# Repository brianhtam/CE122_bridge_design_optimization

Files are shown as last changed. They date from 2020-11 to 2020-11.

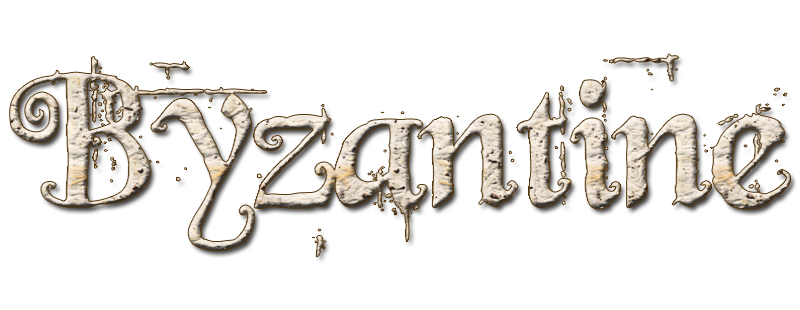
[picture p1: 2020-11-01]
Design Dwg/drawing set 0426/byzantine-553485bc295ea.png

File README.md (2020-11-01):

# University of California, Berkeley

CE 122/123L Bridge Design

# Project Team



**Brian Tam**

**Omar Natouf**

**Shien Jinn Sam**

**Yanlong Ma**

**Yiqiu Zhang**

##

## **Table of Contents**

**[Table of Contents](#_f7xz7zsjwv2b) 2**

**[Letter of Transmittal](#_xhpnu6qg48wh) 3**

**[Financial Proposal](#_yx2o4zm9mrrj) 5**

[Overview](#_aqlsbv7fhpvq) 5

[Cable Costs](#_o17h3vvil44b) 5

[Deck Costs](#_dh3ztm5w0bez) 6

[Tower Costs](#_s972q8khpf2) 7

[Total Costs per Material](#_b7bybf2inuhd) 7

**[Technical Proposal](#_st1wws806zix) 8**

[General Project Description](#_1rhd1lc7gizo) 8

[Structural system](#_jgtkp7muid0m) 8

[Loading criteria and assumption](#_r6sjckvptk4v) 9

[Materials](#_yjlk839i16uc) 9

[Geotechnical](#_2ylj1osfg9p6) 10

[Design of special conditions / elements](#_7mhoiul97b6n) 10

[i.Superstructure](#_jvqc4qcoaiqa) 10

[ii.Front Cable](#_czys5ons2eut) 17

[iii.Back Cable](#_febw9687uqyy) 18

[iv.Pylon](#_nsjcbofvci24) 18

[Foundation](#_ym1lxph0stmt) 19

[East side foundation](#_q6vr1uheaz0p) 19

[Abutment](#_579va1yglpyk) 20

[Constructability](#_equ7trvwbor7) 25

**[Appendix](#_nmife3doaf2) 32**

##

1.
## Letter of Transmittal

Davis 502

Berkeley, CA 94720

Yanlong Ma, PhD

April 28th 2017

Professor Stephen Mahin

Professor of Civil Engineering,

University of California, Berkeley

Berkeley, Ca 94720

Dear Professor Mahin,

We are Byzantine, a structural engineering firm specializing in bridge design and construction. It has come to our attention recently, that there is an open design bid for the proposed J St. Bridge. Our team, consisting of professionally licensed structural engineers, is writing to submit our design proposal for the proposed replacement bridge.

Given the geographical conditions of the site and the required bridge span, we are proposing an asymmetric cable stayed bridge. Our extensive design considerations-to be expounded on briefly- captures the combined interests of all stakeholders in this project;environment, safety, constructability, and financing.

Our basic design considerations were to provide a safe, easily constructable and economical design that would have minimal disruption to the existing environment while maintaining a pleasing design aesthetic. These considerations are paramount as societies increasingly value reliability and sustainability. They are also an exercise in practicality. Due to the enormous financing costs of such structures, having an economical and easily implementable design would expedite the financing process and reduce the economic disruption of local communities typically associated with longer construction schedules. The site requires that the proposed structure span 525 feet over the Sacramento River. For this particular geometry, it is determined that a cable stayed design would be most economical. Furthermore, having a suspension based superstructure negates the need for multiple supporting structures and columns within the river below, easing construction and reducing the environmental impact on the existing river ecosystem.

Our design utilizes an asymmetric support system, with two towers on a single bank bearing the load of the entire deck. This design, while unusual has several key structural advantages- having the supporting tower be placed on the bank negates the need for expensive construction equipment and procedures to be carried out to construct the structure in the river below. Cable stayed designs are also much more efficient, having significantly lower weights than their compression arch counterparts, increasing its seismic reliability. We have taken great care to ensure that all parts of our bridge meet a minimum factor of safety of 1.5.

Cables are strung along the tower in parallel to suspend the deck above the water at the required height. The parallel cable arrangement allows for loading to be evenly distributed along the cables and along the tower. Parallel backties from the tower to a ground anchor on the bank help stabilize the tower against the moment generated by the bridge load. The deck in contact with the bank opposite of the towers are attached on rollers to allow it to freely slide and prevent tension in the concrete deck.

When performing the modelling of our structure, we examined two main loading conditions: dead load and moving live load. Under the dead load conditions, we examined the deformations generated on the deck and tower of our SAP model and applied the required pre-stresses. We repeated a simulation of moving load conditions to examine or structure&#39;s behavior with moving cars on it. On both accounts, our design passes the stipulated deflection conditions.

Construction will be expedited by using prefabricated steel decks that will be consecutively suspended by a crane, and connected by cables to the supporting tower. Due to the linear nature of this procedure, the same process can be repeated with minimal procedure alterations as the decks get suspended. The estimated cost of our proposal is $53,254,439.48. We believe that this is a justified investment, since the proposed development will increase the transit capacity of the region, while upgrading the existing transportation infrastructure to be more seismically resilient and aesthetically pleasing. Increase capacity will drive economic growth within the region while increasing the productivity of commuters as they spend less time stuck in traffic. Given that no major seismic event has occurred in a while, we believe the improved structural reliability is a timely and necessary upgrade in anticipation and mitigation of future risks. We hope that our design and the technical details it entails in this report will convince you of the viability of our solutions.

Sincerely,

Yanlong Ma, PhD

CEO, Byzantine Structural Solutions

1.
## Financial Proposal

### Overview

For cost estimation, we took considerations for the components of the cables, deck, and tower of the bridge.

Our cables were #37 and back ties were #127 in diameter. The length and diameters of each cable were used to calculate the volume of grad 270 cable steel, and we used the density of grade 270 steel to calculate our total cable weight. Our weight of steel was multiplied by the cost per unit weight for the cables to obtain the net cost of our cable system, approximately $935,567 for the material costs and $1,247,423 for the construction of the cables.

The tower consists of two reinforced concrete pylons, connected by two concrete bracings. The volume of these four components were geometrically estimated. The tower, in combination with the 8&quot; slab in our deck consists of the main reinforced concrete components of our bridge and in total sums up to around 215,890 cubic feet of structural concrete costing $6,476,711.

For our rebar estimations we took the volume of structural concrete and assumed that 2% of the volume to be filled with steel rebar with a density of 490 pcf. In total, our structural rebar costs $12,694,354. The steel components were calculated to be $14,177,947 and $17,722,434 for the furnish and erect costs respectively. A 5% bonus was added to account for steel bolts, connections, and other extra components.

In total, our bridge costs a total of $53,254,439.

### Cable Costs

| Cable # | Length (ft) | # of Strands | Cable Diameter(mm) | Cable diameter (ft) | Volume of cable (cubic feet) | Density (pcf) | Weight (LB) |
| --- | --- | --- | --- | --- | --- | --- | --- |
| 1 | 603 | 37 | 109.9 | 0.3605643 | 61.5458267 | 374 | 23018.13919 |
| 2 | 567 | 37 | 109.9 | 0.3605643 | 57.9398202 | 374 | 21669.49275 |
| 3 | 532 | 37 | 109.9 | 0.3605643 | 54.33382177 | 374 | 20320.84934 |
| 4 | 497 | 37 | 109.9 | 0.3605643 | 50.72783315 | 374 | 18972.2096 |
| 5 | 461 | 37 | 109.9 | 0.3605643 | 47.12185658 | 374 | 17623.57436 |
| 6 | 426 | 37 | 109.9 | 0.3605643 | 43.51589506 | 374 | 16274.94475 |
| 7 | 391 | 37 | 109.9 | 0.3605643 | 39.90995266 | 374 | 14926.32229 |
| 8 | 356 | 37 | 109.9 | 0.3605643 | 36.30403509 | 374 | 13577.70912 |
| 9 | 320 | 37 | 109.9 | 0.3605643 | 32.69815055 | 374 | 12229.10831 |
| 10 | 285 | 37 | 109.9 | 0.3605643 | 29.09231135 | 374 | 10880.52444 |
| 11 | 250 | 37 | 109.9 | 0.3605643 | 25.4865367 | 374 | 9531.964725 |
| 12 | 214 | 37 | 109.9 | 0.3605643 | 21.88085853 | 374 | 8183.441089 |
| 13 | 179 | 37 | 109.9 | 0.3605643 | 18.27533394 | 374 | 6834.974894 |
| 14 | 144 | 37 | 109.9 | 0.3605643 | 14.67007618 | 374 | 5486.608491 |
| 15 | 108 | 37 | 109.9 | 0.3605643 | 11.06534605 | 374 | 4138.439423 |
| 16 | 73 | 37 | 109.9 | 0.3605643 | 7.461908268 | 374 | 2790.753692 |
| 17 | 38 | 37 | 109.9 | 0.3605643 | 3.863380707 | 374 | 1444.904384 |
| 18 | 235 | 127 | 204.1 | 0.6696194 | 82.75865648 | 374 | 30951.73752 |
| 19 | 194.5 | 127 | 204.1 | 0.6696194 | 68.4959944 | 374 | 25617.50191 |
| 20 | 154 | 127 | 204.1 | 0.6696194 | 54.23333233 | 374 | 20283.26629 |
| 21 | 113 | 127 | 204.1 | 0.6696194 | 39.79458801 | 374 | 14883.17592 |
| 22 | 72.5 | 127 | 204.1 | 0.6696194 | 25.53192593 | 374 | 9548.9403 |
|
 |
 |
 |
 |
 |
 |
 | **309188.5828** |
|
 |
 |
 |
 |
 |
 |
 | **Total Weight** |

### Deck Costs

|
 |
 |
 | Total Self Weight(kip) |
| --- | --- | --- | --- |
| Deck | 8&quot; Slab | Concrete | 4462.5 |
| Deck | Pavement , needs data |
 |
 |
| Deck | Stringers | Steel W30x 391 | 1055.7 |
| Note A on dwg | Girder Type 1 | Built-up: 18x4 flange, 3 x 32 web | 1298.08685 |
| Note B on dwg | Girder Type 2 (Not Used) | Steel W30x261 | 0 |
| Deck | Bottom Deck (Not Used) | Steel 40 in x 40 in x 2.5 in | 0 |
| Note C on dwg | Edge Girder | Box Steel HSS 5 x 4.5 x 0.75 in | 1190.7 |

### Tower Costs

| Pylon diameter 1 | 3 | ft |
| --- | --- | --- |
| Pylon diameter 2 | 18 | ft |
| Pylon Height | 228 | ft |
| Pylon Volume | 92400.44508 | ft^3 |
| **Tower as a whole** | 184800.8902 | ft^3 |
| **Concrete Bracing 1** | 689.1863063 | ft^3 |
| **Concrete Bracing 2** | 650.30913 | ft^3 |

### Total Costs per Material

| Material | Unit price | In Units Of | Unit (LB or CF) | Material Cost |
| --- | --- | --- | --- | --- |
| Furnish Structural Steel | 4 | $ / LB | 3544486.85 | $14,177,947.40 |
| Erect Structural Steel | 5 | $ / LB | 3544486.85 | $17,722,434.25 |
| Furnish Cable System | 4.5 | $ / LB | 207903.9609 | $935,567.82 |
| Erect Cable System | 6 | $ / LB | 207903.9609 | $1,247,423.77 |
| Bar Reinforcement Steel (2% volume of structural concrete) | 6 | $ / LB | 2115725.779 | $12,694,354.67 |
| Structural Concrete | 30 | $ / CF | 215890.3856 | $6,476,711.57 |
|
 |
 |
 |
 | $53,254,439.48 |
|
 |
 |
 |
 | Total Cost |

1.
## Technical Proposal

### General Project Description



The bridge will replace the existing J St, Bridge near CSU Sacramento over the American River (38.568903, -121.423128). The proposed new bridge will carry 6 lines of traffic connecting J St. and Fair Oaks Blvd.

### Structural system

The type of the bridge is **cable stay bridge** with two towers on the east side of the river bank. The two tower are parallel and tilt to the east side. Both the towers are cone shapes and same design features. The Table 3.1 shows some dimensions of the design bridge.

**Table 3.1: Design Dimensions**

| Main Structure | Category | Size | Unit |
| --- | --- | --- | --- |
| Length | Deck | 525 | ft |
| Width | Deck | 89 | ft |
| Height | Tower | 228 | ft |
| Tilt Angle | Tower | 15 | -- |
| Diameter (Bottom) | Tower | 18 | ft |
| Diameter (Top) | Tower | 4 | ft |
| Height | Abutment | 22 | ft |

Codes and references

The design confirms the:

-ACI 318: Building Code Requirements for Structural Concrete (ACI)

-AISC Steel Construction Manual, 14th Edition (AISC)

- Some details part follow the special guides.

### Loading criteria and assumption

The design length of the main bridge is 525 feet and 50 feet above the water level. The service distributed live load is 0.64 kip / ft / lane and two 25 kip axles per lane spaced at 4 feet.

The reductor used for live load is 0.65. Follow the load combination in ACI, the Load = 1.2 Dead Load + 1.6 Live Load. The tandem load place on the left end of the bridge which will produce the extreme force effect.

#### Materials

The Materials used for the bridge design are summarized in the Table 3.2 below.

**Table 3.2 Material Properties**

| Member | Material | Grade | Unit |
| --- | --- | --- | --- |
| Deck | Concrete | 8 | ksi |
| Deck | Steel Rebar | 60 | ksi |
| Stringer | Steel | 50 | ksi |
| Girder | Steel | 50 | ksi |
| Edge Girder | Steel | 50 | ksi |
| Cable | Steel | 270 | ksi |
| Tower | Concrete | 6 | ksi |
| Tower | Steel Rebar | 60 | ksi |
| Abutment | Concrete | 6 | ksi |
| Abutment | Steel Rebar | 60 | ksi |
| Fundation | Concrete | 6 | ksi |

#### Geotechnical

The preliminary geotechnical assumption show in the Table 3.3 below.

Table 3.3: Geotechnical Assumption

| Limit State | Nominal Bearing Resistance, qn |
| --- | --- |
| Service | 20 ksf |
| Strength | 50 ksf |

#### Design of special conditions / elements

Basically, the bridge will carry the dead load of itself, the distributed live load, and a point lived load. The service distributed live load is 0.64 kip / ft / lane and two 25 kip axles per lane spaced at 4 feet.

For both distributed live load and dead load, the loads are transformed into distributed load (kips / ft2) to do the calculation.

The live load impact factor used for this bridge is 0.65, and the combination factors for live load and dead load are 1.6 and 1.2 (L = 1.2 LD + 1.6 LL).

The calculation of loads for superstructure is shown in the Appendix Excel file (A1).

Design of typical elements

##### i.Superstructure

There are 4 components for the superstructure: concrete slab, steel stringer, steel girder, and steel edge girder. There properties are shown in the Table below.

Superstructure Properties

| Components | Material | Grade | Notes |
| --- | --- | --- | --- |
| Slab | Concrete | 8 ksi | Steel ratio in the concrete is 2% |
| Steel Rebar | 60 ksi |
| Stringer | Steel | A572 (50 ksi) | W30 391 |
| Girder | Steel | A572 (50 ksi) | Built up W shape 22&quot;4&quot; Flange, 4&quot;22&quot; Web |
| Edge Girder | Steel | A572 (50 ksi) | Built up HSS, 12&quot;78&quot;2&quot; for deck #1 - #8, 24&quot;78&quot;2&quot; for deck # 9 - #17 |

The capacity design for each member basic follow the AISC codes. For stringer and girder, the local buckling and lateral buckling are the mainly checking parts. For Edge girder, the overall buckling is the key factor to determine the capacity. For all the member, the required shears are much smaller than the capacity.

The compression elements checking using the Table below.



Equation used for Lateral buckling



Where



Shear Design







Equation for Overall buckling



Where Fe determined by Euler&#39;s Buckling Equation 

K = 1.0 (pin-pin condition) for edge girder

The table used to check local buckling



The capacities of the members are summarized in the table below.

| | Stringer | Girder | Edge Girder |
| --- | --- | --- | --- |
| Local Buckling (k-ft) | Compact | Compact | Compact |
| Overall bucking (kips) | -- | -- | 16045\* |
| Lateral Buckling (k-ft) | 5267 | 8955 | 13911 |
| Shear (kips) | 1554 | 4560 | 4920 |
| \*Note: The concrete slab will carry part of compression (474 ksi) |

There are shear studs will connect the concrete slab to the edge girder to resist a part compression in the edge girder.

Because the compression will decrease along the edge girder, there are two type of edge girder. The strong one has a large capacity with dimension 24&quot; \* 78&quot; \* 2&quot;, and the small one has a dimension 12&quot; \* 78&quot; \* 2&quot;.

The figure shows the axial compression along the girder.



##### ii.Front Cable

The cable consists with the seven-wire strand. Some properties of the material are listed below.

Table: Properties of Seven-Wire Strand Cable

| Seven-Wire Strand Cable | Properties |
| --- | --- |
| Diameter | 15.7 mm |
| Effective Area | 150 mm |
| Grade | 270 |
| Tensile Capacity | 62.775 ksi |

The front cable designed for the bridge consisted with 37 seven-wire strand. The total tensile capacity for the front cable is 2323 ksi.

There are 16 front cables (each side) to carry all the load from the deck and the girders. The ratio of height over length is 1:2.5.

##### iii.Back Cable

The back cable consisted with the same material as the front one. The number of strand for each back cable is 127, which will create a 7972 ksi tensile capacity.

There are 6 back cables (each side) to balance the moment created by the front cable.

##### iv.Pylon

There are two parallel pylons both on the east side of the river. The two pylons have the exact same design. The basic dimensions for the pylons are listed in the Table below.

Table: Properties of Pylons

| Pylon (each) | Quantity |
| --- | --- |
| Shape | Cone |
| Height (ft) | 228 |
| Length (ft) | 236.04 |
| Tilt Angle (Deg) | 15 |
| Bottom Diameter (ft) | 18 |
| Top Diameter (ft) | 4 |
| Materials | Steel (ksi) | 60 | Steel ratio is 0.02 |
| Concrete (ksi) | 6 |
| Weight (ksi) | 4000 |

The capacity design for each member basic are very close to the design method above. The moment of the pylons and the compression of the pylons are the main design parts.

The moment design use the equation . The equation basically use for rectangular box design. Therefore, b = r, d = 2r for this design.

The axial force design follow the same step above (overall buckling), but change the Euler number K to 2 (fix and free).

The cross beam between the pylons only resist the compression force. Therefore, check the overall buckling same as above.

The design capacities are shown below.

Table: Pylons

| Variables | Quantity |
| --- | --- |
| Moment | 4.8\*10^6 k-ft |
| Axial Force | 9.6\*10^4 kips |
| Axial Force (Cross Beams) | 5584 kips |

### Foundation

The foundation systems consisted with 2 parts. The abutment for the west side and the deep foundation on the east side of the river.

#### East side foundation

Because the pylons are on the east side of the bridge, the compression from the edge girder will cause a large shear and compression on the east side bank. Therefore, the east side cannot use the soil to resist the forces. Meanwhile, the back cable need to be anchored on the east side foundation.

The design is to use concrete fill the top 10 feet ground surface to resist the compression force. However, for the back part, the foundation should touch the bedrock and anchored the back cable into the rock and use concrete to enforce the connection part.

####

####

#### **Abutment**

The left side of the abutment will not resist the horizontal force from the superstructure. Therefore, the design only resist the load from the last segment of the deck and the soil pressure from the bank.

The detail designs are shown below.

The abutment is a reinforced concrete abutment with stem of 20 feet height and and 4 feet thickness. The type of abutment we choose is open end short stem seat. The seat width is thirty six inches wide. . The foundation for the abutment is two feet deep and ten by ten feets.The ratio of steel reinforcement is 0.2 percent.

We design the foundation of the abutment based on the allowable soil pressure at service area. Then we used the . We evaluate the one way and two ways shear and the flexure of the foundation. Based on our calculation we needed 20 #6, more details for the anchorage length and bearing between the stem and footing to be done.

The stem design was based on the soil pressure on the wall. We designed the stem to be adequate for shear and moment at the bottom which is the critical part.

The equations used are below.

Vc=0.75\*2\*Sqrt(4000)\*b\*d

Mu=0.9\*As\*fy\*b\*d(1-0.59\*As\*fy/(fc\*b\*d))

Vu=0.75\*Vc

The load analysis we have done is based on AASHTO 2010.

**Undeformed Shape**



**Figure. 1**

Load combination one

A live load of 0.64 k/ft/lane and two 25k/lane four feet apart to represent a random cars moving on the bridge. During this load combination we do not account to any wind load.

Load combination two

The dead load with 1.25 factor represent the gravity load of the structure with safety factor.

Load combination three

The other load combination we used is the earthquake load of 0.15 of Deal load.

Results:

Moving load deflection **Figure. A**

Moving load and dead load combination deflection **Figure. B**

Dead load deflection **Figure.C**

The model deflection **Figure. D**



**Figure. A**



**Figure. B**



**Figure.C**



Figure. D

The lane loads **Figure.E**



**Figure. E**

####

####

####

####

####

####

####

####

####

#### **Constructability**

The construction of the cable stay bridge.

Step one:

Construct the adequate foundations and the abutment

Step two:

Construct the pylons

Step three:

Add the cable based on the deck constructions

Step four:

Add the deck sections of 60 ft long

The deck and cable construction will go hand by hand.

We recommended a use of cranes and ships to construct the deck which allow for minimum risk.

**Design Drawings**

Elevation view of proposed structure



Plan view of proposed structure:



Tower Cross Section



Bridge Deck Cross Section



Bridge Framing Plan



Cable



1.
## Appendix

Excel Load Calculations Sheet



**Matlab Codes and Design Tools**

Beam Capacity Check:

clear all; clc

Lb = 25\*12;

E = 29000; Fy = 50;

A = 115; tf = 2.44; bf = 15.6; h = 26.5; tw = 1.36 ; d = 33.2; Cb = 1.14;

ry = 0; %% if do not know, ry = 0

rts = 0; %% if do not know, rts = 0

J = 0; %% if do not know, J = 0

Sx = 1250; %% if do not know, Sx = 0

Z = 0;

h0 = d-tf;

if ry==0

Iy = tf\*bf^3/6;

ry = (Iy/A)^.5;

end

if J == 0;

J = 1/3\*(bf\*tf^3\*2 + h\*tw^3);

end

if Sx == 0

y = (tf\*2+h)/2;

Ix = (bf\*tf^3\*2 + tw\*h^3)/12+ bf\*tf\*(y-tf/2)^2\*2;

Sx = Ix / y;

end

if rts ==0

Iy = tf\*bf^3/6;

rts = (Iy\*h0/2/Sx)^.5;

end

if Z == 0

y = (tf\*2+h)/2;

Z = tf\*bf\*(y-tf/2)\*2 + h/2\*tw\*h/4\*2;

end

Mp = Z \* Fy;

%%%%%%%%%%%%%%%%%%%%%%%%%%%%%%%%%

Lp = 1.76\*ry\*(E/Fy)^.5;

Lr = 1.95\*rts\*E/(0.7\*Fy)\* (J/(Sx\*h0)+((J/(Sx\*h0))^2+6.76\*(0.7\*Fy/E)^2)^.5)^.5;

if Lb \&lt;= Lp

disp(&#39;case 1&#39;);

Mn = Mp;

elseif Lb \&lt;= Lr

Mn = Cb\*(Mp - (Mp-0.7\*Fy\*Sx)\*((Lb-Lp)/(Lr-Lp)))

if Mn \&gt;= Mp

Mn = Mp;

end

disp(&#39;case 2&#39;);

else

Mn = Cb \* Sx\*pi^2\*E/(Lb/rts)^2\* (1+0.078\*J/Sx/h0\*(Lb/rts)^2)^.5

if Mn \&gt;= Mp

Mn = Mp;

end

disp(&#39;case 3&#39;);

end

disp(&#39;Mn in feet&#39;);

Mn = Mn /12

Mu = 0.9 \* Mn

Lateral Buckling

clear all; clc

% require 7371

Lb = 85\*12;

E = 29000; Fy = 50;

A = 376; tf = 2; bf = 24; tw = 4; d = 78; Cb = 1.14;

h = d - 2\*tf;

ry = 0; %% if do not know, ry = 0

rts = 0; %% if do not know, rts = 0

J = 0; %% if do not know, J = 0

Sx = 0; %% if do not know, Sx = 0

Z = 0;

h0 = d-tf;

if ry==0

Iy = tf\*bf^3/6;

ry = (Iy/A)^.5;

end

if J == 0;

J = 1/3\*(bf\*tf^3\*2 + h\*tw^3);

end

if Sx == 0

y = (tf\*2+h)/2;

Ix = (bf\*tf^3\*2 + tw\*h^3)/12+ bf\*tf\*(y-tf/2)^2\*2;

Sx = Ix / y;

end

if rts ==0

Iy = tf\*bf^3/6;

rts = (Iy\*h0/2/Sx)^.5;

end

if Z == 0

y = (tf\*2+h)/2;

Z = tf\*bf\*(y-tf/2)\*2 + h/2\*tw\*h/4\*2;

end

Mp = Z \* Fy;

%%%%%%%%%%%%%%%%%%%%%%%%%%%%%%%%%

Lp = 1.76\*ry\*(E/Fy)^.5;

Lr = 1.95\*rts\*E/(0.7\*Fy)\* (J/(Sx\*h0)+((J/(Sx\*h0))^2+6.76\*(0.7\*Fy/E)^2)^.5)^.5;

if Lb \&lt;= Lp

disp(&#39;case 1&#39;);

Mn = Mp;

elseif Lb \&lt;= Lr

Mn = Cb\*(Mp - (Mp-0.7\*Fy\*Sx)\*((Lb-Lp)/(Lr-Lp)))

if Mn \&gt;= Mp

Mn = Mp;

end

disp(&#39;case 2&#39;);

else

Mn = Cb \* Sx\*pi^2\*E/(Lb/rts)^2\* (1+0.078\*J/Sx/h0\*(Lb/rts)^2)^.5

if Mn \&gt;= Mp

Mn = Mp;

end

disp(&#39;case 3&#39;);

end

disp(&#39;Mn in feet&#39;);

Mn = Mn /12

Mu = 0.9 \* Mn

Local Buckling Check

bf = 11.6; tf = 1.91;

z = 490; Fy = 50; Sx = 419; h = 15.5; tw = 1.06; E = 29000;

lam\_pf = 0.38\*(E/Fy)^0.5; lam\_rf = (E/Fy)^0.5;

Mp = z\* Fy

lamda = bf/2/tf;

if lamda \&lt;= lam\_pf

Mn = Mp / 12

elseif lamda \&lt;= lam\_rf

Mn = Mp - (Mp - 0.7\*Fy\*Sx)\*((lamda-lam\_pf)/(lam\_rf-lam\_pf)) / 12

else

kc = 4 / (h/tw)^0.5;

if kc \&lt; 0.35

kc = 0.35;

elseif kc\&gt; 0.76

kc = 0.76;

end

Mn = 0.9\*E\*kc\*Sx / lamda^2 / 12

end

Overall Buckling

clear all; clc;

Kx = [1.0];

Ky = [1.0];

L = [89\*12];

rx = 12; ry = 12;

E = 3600; Fy = 6; Ag = 12.57\*144;

KL\_r = max([Kx.\*L/rx; Ky.\*L/ry]);

Fe = pi^2\*E./(KL\_r).^2;

for i = 1:numel(KL\_r)

if KL\_r(i) \&lt;= 4.71\*(E/Fy)^.5

Fcr(i) = 0.658^(Fy/Fe(i)) \* Fy;

else

Fcr(i) = .877\*Fe(i);

end

end

Pu = 0.9 \* Fcr \* Ag

Buckling Check

clear all; clc;

Kx = [1.2 2 2 2];

Ky = [.8 1 1 1];

L = [144 17\*12+6 14\*12+6 144];

rx = 5.51; ry = 3.13;

E = 29000; Fy = 50; Ag = 35.2;

KL\_r = max([Kx.\*L/rx; Ky.\*L/ry])

Fe = pi^2\*E./(KL\_r).^2;

for i = 1:numel(KL\_r)

if KL\_r(i) \&lt;= 4.71\*(E/Fy)^.5

Fcr(i) = 0.658^(Fy/Fe(i)) \* Fy;

else

Fcr(i) = .877\*Fe(i);

end

end

Box girder flexural iterative design tool

Pu = 0.9 \* Fcr \* Ag

E=29000; %Specify Elastic Modulus

Fy=50; %Specify Fy

d=40;%specify depth in inches

tf=2.5;%specify flange thickness in inches

bf=40;%specify breadth of flange in inches

tw=2.5;%specify thickness of web in inches

h=d-tf\*2;

d1=d-tf/2;

d2=bf/2;

A1=2\*bf\*tf;

A2=4\*(h/2)\*tw;

%Check Local buckling of Compression Flange

lambda=bf/tf;

lambdapf=1.12\*sqrt((E/Fy));

lambdarf=1.4\*sqrt(E/Fy);

% Variables

Ixx=2\*bf\*(tf^3)/12 +bf\*tf\*(bf/2-tf)+2\*tw\*(h^3)/12 +h\*tw\*(h/2-tw); %Check the d with yanlong for Ad^2

beff=1.92\*tf\*sqrt(E/Fy)\*(1-(0.38/(bf/tf))\*sqrt(E/Fy));

Seff=Ixx/beff;

Zx=0.25\*(bf\*((h+2\*tw)^2)-(bf-2\*tf)\*h^2); %Z outer rectangle- Z inner rectangle

Mp=Fy\*Zx; %Mp=Fy\*Zx

Sx=Ixx/(h/2-tf);

%Check for local buckling

if lambda\&lt;lambdapf

result=&#39;Section is Compact, No Local Buckling&#39;

Mn=Mp;

elseif lambda\&gt;lambdapf &amp;&amp; lambda\&lt;lambdarf

result=&#39;Inelastic Flange Local Buckling&#39;

Mn=Mp-(Mp-Fy\*Sx)\*(3.57\*bf/tf)\*(sqrt(Fy/E)-4.0);

else

result=&#39;Inelastic Flange Local Buckling&#39;

Mn=Fy\*Seff;

end

Mn=num2str(0.9\*Mn/12); %Mu in Kip foot, multiplied by safety factor 0.9

Mu=[&#39;Mu is &#39;,Mn,&#39; kipfoot&#39;]

Shear Checks

I\_roll = 0; %% 1 if rolled I shape, 0 others

stiffen = 0; %% 0 if unstiffened, other 1

E = 29000; Fy = 50;

Cv = 0; %% initial

h = 26.5; tw = 1.36; bf = 15.6; tf = 2.44; %a = 25; % spacing

if h/tw \&lt;= 2.24\*(E/Fy)^.5

phi = 1;

Cv = 1;

else

phi = 0.9;

end

if h/tw \&lt; 260 &amp;&amp; stiffen == 0

kv = 5;

else

kv = 5 + 5/(a/h)^2;

if a/h \&gt;3 || a/h \&gt; (260/(h/tw))^2

kv = 5;

end

end

if Cv == 1 || h/tw \&lt;= 1.1\*(kv\*E/Fy)^.5

Cv = 1;

elseif h/tw \&lt;= 1.37 \* (kv\*E/Fy)^.5

Cv = 1.1\*(kv\*E/Fy)^.5 / (h/tw);

else

Cv = 1.51\*E\*kv / ((h/tw)^2\*Fy);

end

Aw = (h + 2\*tf)\*tw;

Vn = 0.6\*Fy\*Aw\*Cv;

Vu = phi\*Vn

%% check stiffened

J = 2.5 / (a/h)^2 -2;

Iww = a \* tw^3\* J

1

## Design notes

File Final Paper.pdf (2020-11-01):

University of California, Berkeley CE 122/123L Bridge Design

# Byzantine

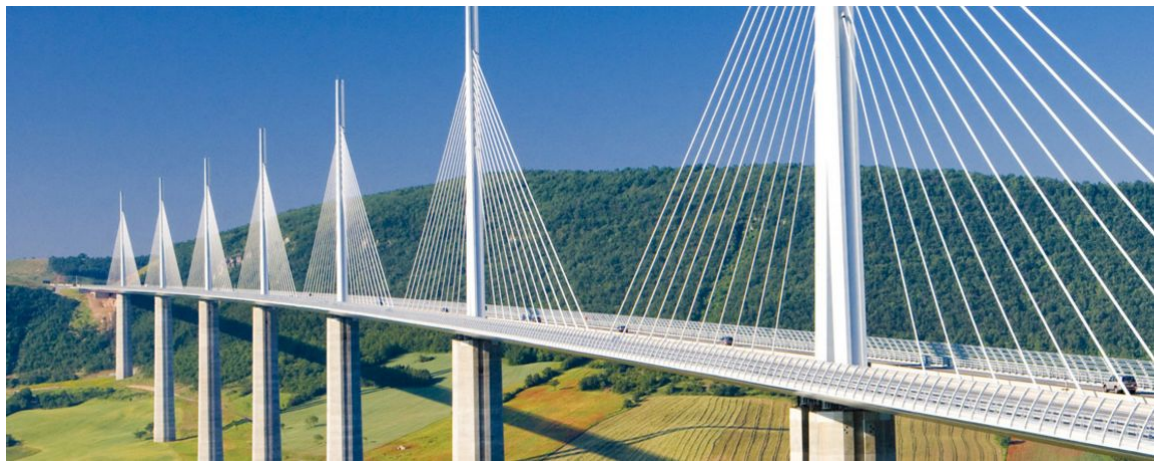
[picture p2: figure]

Brian Tam
Omar Natouf
Shien Jinn Sam
Yanlong Ma
Yiqiu Zhang

## Table of Contents

Table of Contents | 2
Letter of Transmittal | 3
Financial Proposal | 5
Overview | 5
Cable Costs | 5
Deck Costs | 6
Tower Costs | 7
Total Costs per Material | 7
Technical Proposal | 8
General Project Description | 8
Structural system | 8
Loading criteria and assumption | 9
Materials | 9
Geotechnical | 10
Design of special conditions / elements | 10
i.Superstructure | 10
ii.Front Cable | 17
iii.Back Cable | 18
iv.Pylon | 18
Foundation | 19
East side foundation | 19
Abutment | 20
Constructability | 25
Appendix | 32

## I. Letter of Transmittal

Davis 502
Berkeley, CA 94720
Yanlong Ma, PhD

April 28th 2017

Professor Stephen Mahin
Professor of Civil Engineering, University of California, Berkeley
Berkeley, Ca 94720

Dear Professor Mahin,
We are Byzantine, a structural engineering firm specializing in bridge design and construction. It has come to our attention recently, that there is an open design bid for the proposed J St. Bridge. Our team, consisting of professionally licensed structural engineers, is writing to submit our design proposal for the proposed replacement bridge.
Given the geographical conditions of the site and the required bridge span, we are proposing an asymmetric cable stayed bridge. Our extensive design considerations-to be expounded on briefly- captures the combined interests of all stakeholders in this project;environment, safety, constructability, and financing.
Our basic design considerations were to provide a safe, easily constructable and economical design that would have minimal disruption to the existing environment while maintaining a pleasing design aesthetic. These considerations are paramount as societies increasingly value reliability and sustainability. They are also an exercise in practicality. Due to the enormous financing costs of such structures, having an economical and easily implementable design would expedite the financing process and reduce the economic disruption of local communities typically associated with longer construction schedules. The site requires that the proposed structure span 525 feet over the Sacramento River. For this particular geometry, it is determined that a cable stayed design would be most economical. Furthermore, having a suspension based superstructure negates the need for multiple supporting structures and columns within the river below, easing construction and reducing the environmental impact on the existing river ecosystem.
Our design utilizes an asymmetric support system, with two towers on a single bank bearing the load of the entire deck. This design, while unusual has several key structural advantages- having the supporting tower be placed on the bank negates the need for expensive construction equipment and procedures to be carried out to construct the structure in the river below. Cable stayed designs are also much more efficient, having significantly lower weights than their compression arch counterparts, increasing its seismic reliability. We have taken great care to ensure that all parts of our bridge meet a minimum factor of safety of 1.5.
Cables are strung along the tower in parallel to suspend the deck above the water at the required height. The parallel cable arrangement allows for loading to be evenly distributed along the cables and along the tower. Parallel backties from the tower to a ground anchor on the bank help stabilize the tower against the moment generated by the bridge load. The deck in contact with the bank opposite of the towers are attached on rollers to allow it to freely slide and prevent tension in the concrete deck.
When performing the modelling of our structure, we examined two main loading conditions: dead load and moving live load. Under the dead load conditions, we examined the deformations generated on the deck and tower of our SAP model and applied the required pre-stresses. We repeated a simulation of moving load conditions to examine or structure’s behavior with moving cars on it. On both accounts, our design passes the stipulated deflection conditions.
Construction will be expedited by using prefabricated steel decks that will be consecutively suspended by a crane, and connected by cables to the supporting tower. Due to the linear nature of this procedure, the same process can be repeated with minimal procedure alterations as the decks get suspended. The estimated cost of our proposal is $53,254,439.48. We believe that this is a justified investment, since the proposed development will increase the transit capacity of the region, while upgrading the existing transportation infrastructure to be more seismically resilient and aesthetically pleasing. Increase capacity will drive economic growth within the region while increasing the productivity of commuters as they spend less time stuck in traffic. Given that no major seismic event has occurred in a while, we believe the improved structural reliability is a timely and necessary upgrade in anticipation and mitigation of future risks. We hope that our design and the technical details it entails in this report will convince you of the viability of our solutions.

Sincerely,
Yanlong Ma, PhD
CEO, Byzantine Structural Solutions

## II. Financial Proposal

### Overview

For cost estimation, we took considerations for the components of the cables, deck, and tower of the bridge.
Our cables were #37 and back ties were #127 in diameter. The length and diameters of each cable were used to calculate the volume of grad 270 cable steel, and we used the density of grade 270 steel to calculate our total cable weight. Our weight of steel was multiplied by the cost per unit weight for the cables to obtain the net cost of our cable system, approximately $935,567 for the material costs and $1,247,423 for the construction of the cables.
The tower consists of two reinforced concrete pylons, connected by two concrete bracings. The volume of these four components were geometrically estimated. The tower, in combination with the 8” slab in our deck consists of the main reinforced concrete components of our bridge and in total sums up to around 215,890 cubic feet of structural concrete costing $6,476,711.
For our rebar estimations we took the volume of structural concrete and assumed that 2% of the volume to be filled with steel rebar with a density of 490 pcf. In total, our structural rebar costs $12,694,354. The steel components were calculated to be $14,177,947 and $17,722,434 for the furnish and erect costs respectively. A 5% bonus was added to account for steel bolts, connections, and other extra components.
In total, our bridge costs a total of $53,254,439.

### Cable Costs

Cable # 1 | Length # of (ft) Strands 603 37 | Cable Diameter(mm) 109.9 | Cable diameter (ft) 0.3605643 | Volume of cable (cubic feet) 61.5458267 | Density (pcf) 374 | Weight (LB) 23018.13919
2 | 567 37 | 109.9 | 0.3605643 | 57.9398202 | 374 | 21669.49275

3 | 532 37 | 109.9 | 0.3605643 | 54.33382177 | 374 | 20320.84934
4 | 497 37 | 109.9 | 0.3605643 | 50.72783315 | 374 | 18972.2096
5 | 461 37 | 109.9 | 0.3605643 | 47.12185658 | 374 | 17623.57436
6 | 426 37 | 109.9 | 0.3605643 | 43.51589506 | 374 | 16274.94475
7 | 391 37 | 109.9 | 0.3605643 | 39.90995266 | 374 | 14926.32229
8 | 356 37 | 109.9 | 0.3605643 | 36.30403509 | 374 | 13577.70912
9 | 320 37 | 109.9 | 0.3605643 | 32.69815055 | 374 | 12229.10831
10 | 285 37 | 109.9 | 0.3605643 | 29.09231135 | 374 | 10880.52444
11 | 250 37 | 109.9 | 0.3605643 | 25.4865367 | 374 | 9531.964725
12 | 214 37 | 109.9 | 0.3605643 | 21.88085853 | 374 | 8183.441089
13 | 179 37 | 109.9 | 0.3605643 | 18.27533394 | 374 | 6834.974894
14 | 144 37 | 109.9 | 0.3605643 | 14.67007618 | 374 | 5486.608491
15 | 108 37 | 109.9 | 0.3605643 | 11.06534605 | 374 | 4138.439423
16 | 73 37 | 109.9 | 0.3605643 | 7.461908268 | 374 | 2790.753692
17 | 38 37 | 109.9 | 0.3605643 | 3.863380707 | 374 | 1444.904384
18 | 235 | 127 | 204.1 | 0.6696194 | 82.75865648 | 374 | 30951.73752
19 | 194.5 | 127 | 204.1 | 0.6696194 | 68.4959944 | 374 | 25617.50191
20 | 154 | 127 | 204.1 | 0.6696194 | 54.23333233 | 374 | 20283.26629
21 | 113 | 127 | 204.1 | 0.6696194 | 39.79458801 | 374 | 14883.17592
22 | 72.5 | 127 | 204.1 | 0.6696194 | 25.53192593 | 374 | 9548.9403
| | | | | | | 309188.5828
| | | | | | | Total Weight

### Deck Costs

| | | Total Self Weight(kip)
Deck | 8" Slab | Concrete | 4462.5
Deck | Pavement , needs data
Deck | Stringers | Steel W30x 391 | 1055.7
Note A on dwg | Girder Type 1 | Built-up: 18x4 flange, 3 x 32 web | 1298.08685

Note B on dwg | Girder Type 2 (Not Used) | Steel W30x261 | 0
Deck | Bottom Deck (Not Used) | Steel 40 in x 40 in x 2.5 in | 0
Note C on dwg | Edge Girder | Box Steel HSS 5 x 4.5 x 0.75 in | 1190.7

### Tower Costs

Pylon diameter 1 | 3 | ft
Pylon diameter 2 | 18 | ft
Pylon Height | 228 | ft
Pylon Volume | 92400.44508 | ft^3
Tower as a whole | 184800.8902 | ft^3
Concrete Bracing 1 | 689.1863063 | ft^3
Concrete Bracing 2 | 650.30913 | ft^3

### Total Costs per Material

Material | Unit price | In Units Of | Unit (LB or CF) | Material Cost
Furnish Structural Steel | 4 | $ / LB | 3544486.85 | $14,177,947.40
Erect Structural Steel | 5 | $ / LB | 3544486.85 | $17,722,434.25
Furnish Cable System | 4.5 | $ / LB | 207903.9609 | $935,567.82
Erect Cable System | 6 | $ / LB | 207903.9609 | $1,247,423.77
Bar Reinforcement Steel (2% volume of structural concrete) | 6 | $ / LB | 2115725.779 | $12,694,354.67
Structural Concrete | 30 | $ / CF | 215890.3856 | $6,476,711.57
| | | | $53,254,439.48
| | | | Total Cost

## III. Technical Proposal

### General Project Description

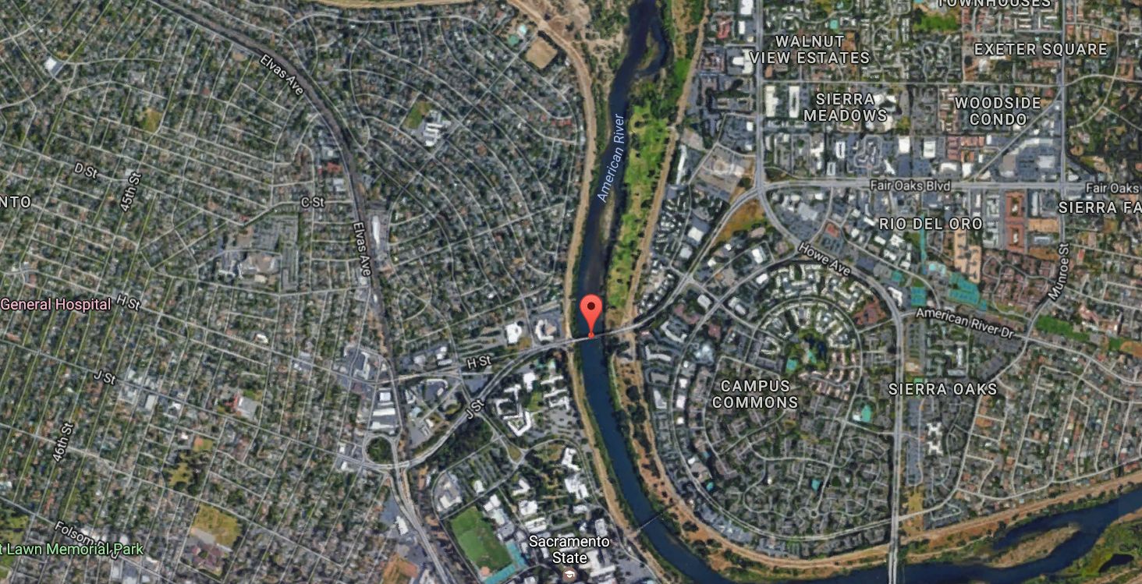
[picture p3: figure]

The bridge will replace the existing J St, Bridge near CSU Sacramento over the American River (38.568903, -121.423128). The proposed new bridge will carry 6 lines of traffic connecting J St. and Fair Oaks Blvd.

### Structural system

The type of the bridge is cable stay bridge with two towers on the east side of the river bank. The two tower are parallel and tilt to the east side. Both the towers are cone shapes and same design features. The Table 3.1 shows some dimensions of the design bridge.

Table 3.1: Design Dimensions
Main Structure | Category | Size | Unit
Length | Deck | 525 | ft
Width | Deck | 89 | ft
Height | Tower | 228 | ft
Tilt Angle | Tower | 15 | --

Diameter (Bottom) | Tower | 18 | ft
Diameter (Top) | Tower | 4 | ft
Height | Abutment | 22 | ft

Codes and references

The design confirms the:
- ACI 318: Building Code Requirements for Structural Concrete (ACI)
- AISC Steel Construction Manual, 14

th Edition (AISC)
- Some details part follow the special guides.

### Loading criteria and assumption

The design length of the main bridge is 525 feet and 50 feet above the water level. The service distributed live load is 0.64 kip / ft / lane and two 25 kip axles per lane spaced at 4 feet. The reductor used for live load is 0.65. Follow the load combination in ACI, the Load = 1.2 Dead Load + 1.6 Live Load. The tandem load place on the left end of the bridge which will produce the extreme force effect.

Materials
The Materials used for the bridge design are summarized in the Table 3.2 below.

Table 3.2 Material Properties
Member | Material | Grade | Unit
Deck | Concrete | 8 | ksi
Deck | Steel Rebar | 60 | ksi
Stringer | Steel | 50 | ksi
Girder | Steel | 50 | ksi
Edge Girder | Steel | 50 | ksi
Cable | Steel | 270 | ksi

Tower | Concrete | 6 | ksi
Tower | Steel Rebar | 60 | ksi
Abutment | Concrete | 6 | ksi
Abutment | Steel Rebar | 60 | ksi
Fundation | Concrete | 6 | ksi

Geotechnical
The preliminary geotechnical assumption show in the Table 3.3 below. Table 3.3: Geotechnical Assumption
Limit State | Nominal Bearing Resistance, qn
Service | 20 ksf
Strength | 50 ksf

Design of special conditions / elements
Basically, the bridge will carry the dead load of itself, the distributed live load, and a point lived load. The service distributed live load is 0.64 kip / ft / lane and two 25 kip axles per lane spaced at 4 feet.
For both distributed live load and dead load, the loads are transformed into distributed load (kips / ft

2
) to do the calculation.
The live load impact factor used for this bridge is 0.65, and the combination factors for live load and dead load are 1.6 and 1.2 (L = 1.2 LD + 1.6 LL

).
The calculation of loads for superstructure is shown in the Appendix Excel file (A1).

Design of typical elements

i.Superstructure
There are 4 components for the superstructure: concrete slab, steel stringer, steel girder, and steel edge girder. There properties are shown in the Table below.

Superstructure Properties
Components | Material | Grade | Notes
Slab | Concrete | 8 ksi | Steel ratio in the concrete is 2%
| Steel Rebar | 60 ksi
Stringer | Steel | A572 (50 ksi) | W30 391
Girder | Steel | A572 (50 ksi) | Built up W shape 22”4” Flange, 4”22” Web
Edge Girder | Steel | A572 (50 ksi) | Built up HSS, 12”78”2” for deck #1 - #8, 24”78”2” for deck # 9 -#17

The capacity design for each member basic follow the AISC codes. For stringer and girder, the local buckling and lateral buckling are the mainly checking parts. For Edge girder, the overall buckling is the key factor to determine the capacity. For all the member, the required shears are much smaller than the capacity.

The compression elements checking using the Table below.

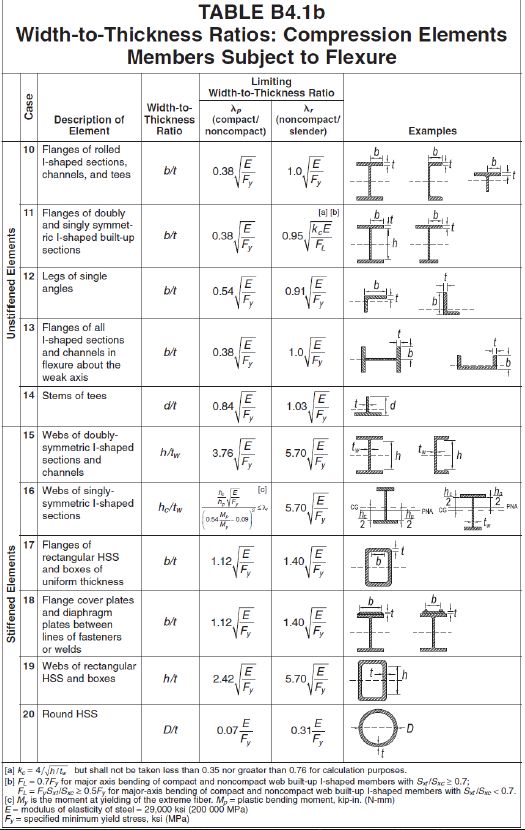
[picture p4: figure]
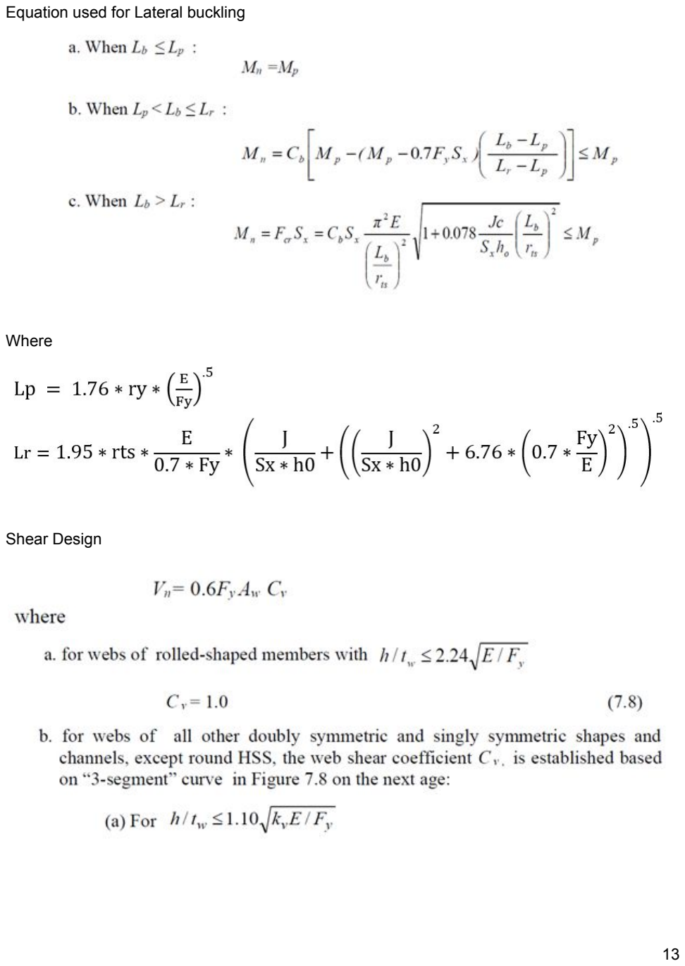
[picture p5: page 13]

Equation used for Lateral buckling

Where

Shear Design

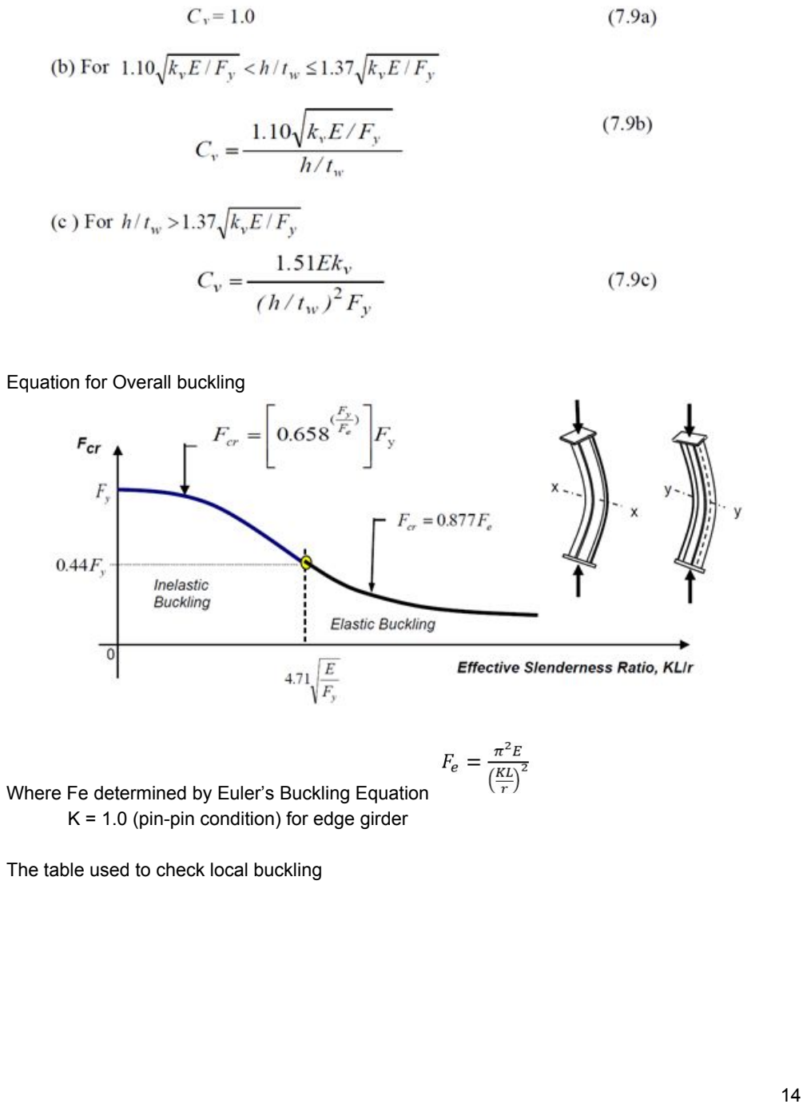
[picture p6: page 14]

Equation for Overall buckling

Where Fe determined by Euler’s Buckling Equation K = 1.0 (pin-pin condition) for edge girder

The table used to check local buckling

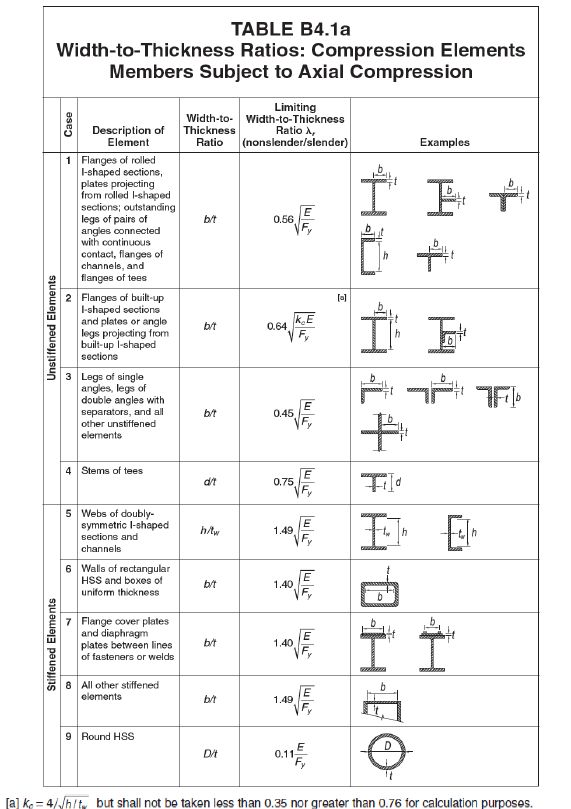
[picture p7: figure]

The capacities of the members are summarized in the table below.
| Stringer | Girder | Edge Girder
Local Buckling (k-ft) | Compact | Compact | Compact
Overall bucking (kips) | -- | -- | 16045*
Lateral Buckling (k-ft) | 5267 | 8955 | 13911
Shear (kips) | 1554 | 4560 | 4920

*Note: The concrete slab will carry part of compression (474 ksi)

There are shear studs will connect the concrete slab to the edge girder to resist a part compression in the edge girder.

Because the compression will decrease along the edge girder, there are two type of edge girder. The strong one has a large capacity with dimension 24” * 78” * 2”, and the small one has a dimension 12” * 78” * 2”.

The figure shows the axial compression along the girder.

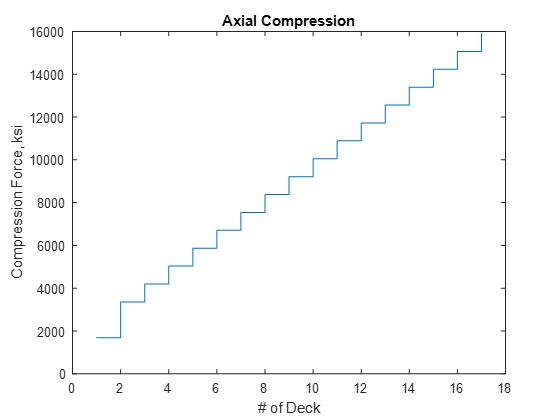
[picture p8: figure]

ii.Front Cable

The cable consists with the seven-wire strand. Some properties of the material are listed below.

Table: Properties of Seven-Wire Strand Cable
Seven-Wire Strand Cable | Properties
Diameter | 15.7 mm
Effective Area | 150 mm
Grade | 270
Tensile Capacity | 62.775 ksi

The front cable designed for the bridge consisted with 37 seven-wire strand. The total tensile capacity for the front cable is 2323 ksi.

There are 16 front cables (each side) to carry all the load from the deck and the girders. The ratio of height over length is 1:2.5.

iii.Back Cable
The back cable consisted with the same material as the front one. The number of strand for each back cable is 127, which will create a 7972 ksi tensile capacity.
There are 6 back cables (each side) to balance the moment created by the front cable.

iv.Pylon
There are two parallel pylons both on the east side of the river. The two pylons have the exact same design. The basic dimensions for the pylons are listed in the Table below.

Table: Properties of Pylons
Pylon (each) | Quantity
Shape | Cone
Height (ft) | 228
Length (ft) | 236.04
Tilt Angle (Deg) | 15
Bottom Diameter (ft) | 18
Top Diameter (ft) | 4
Materials | Steel (ksi) | 60 | Steel ratio is 0.02
| Concrete (ksi) | 6
Weight (ksi) | | 4000

The capacity design for each member basic are very close to the design method above. The moment of the pylons and the compression of the pylons are the main design parts.

The moment design use the equation . The equation basically use for rectangular box design. Therefore, b = r, d = 2r for this design.

The axial force design follow the same step above (overall buckling), but change the Euler number K to 2 (fix and free).

The cross beam between the pylons only resist the compression force. Therefore, check the overall buckling same as above.
The design capacities are shown below.

Table: Pylons
Variables | Quantity
Moment | 4.8*10^6 k-ft
Axial Force | 9.6*10^4 kips
Axial Force (Cross Beams) | 5584 kips

### Foundation

The foundation systems consisted with 2 parts. The abutment for the west side and the deep foundation on the east side of the river.

East side foundation
Because the pylons are on the east side of the bridge, the compression from the edge girder will cause a large shear and compression on the east side bank. Therefore, the east side cannot use the soil to resist the forces. Meanwhile, the back cable need to be anchored on the east side foundation.
The design is to use concrete fill the top 10 feet ground surface to resist the compression force. However, for the back part, the foundation should touch the bedrock and anchored the back cable into the rock and use concrete to enforce the connection part.

Abutment
The left side of the abutment will not resist the horizontal force from the superstructure. Therefore, the design only resist the load from the last segment of the deck and the soil pressure from the bank.
The detail designs are shown below.
The abutment is a reinforced concrete abutment with stem of 20 feet height and and 4 feet thickness. The type of abutment we choose is open end short stem seat. The seat width is thirty six inches wide. . The foundation for the abutment is two feet deep and ten by ten feets.The ratio of steel reinforcement is 0.2 percent.

We design the foundation of the abutment based on the allowable soil pressure at service area. Then we used the q(net) = Pu/A . We evaluate the one way and two ways shear and the flexure of the foundation. Based on our calculation we needed 20 #6, more details for the anchorage length and bearing between the stem and footing to be done.
The stem design was based on the soil pressure on the wall. We designed the stem to be adequate for shear and moment at the bottom which is the critical part.

The equations used are below.
Vc=0.75*2*Sqrt(4000)*b*d
Mu=0.9*As*fy*b*d(1-0.59*As*fy/(fc*b*d))
Vu=0.75*Vc

The load analysis we have done is based on AASHTO 2010. Undeformed Shape

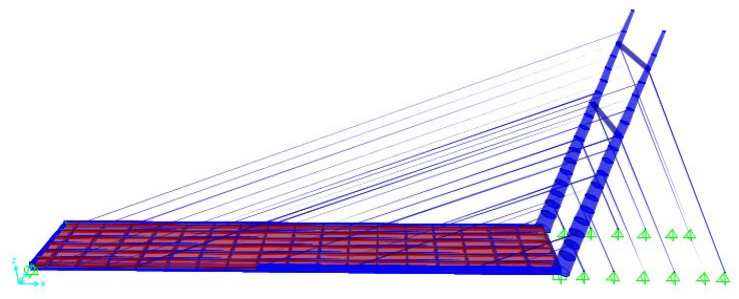
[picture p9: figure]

Figure. 1

Load combination one
A live load of 0.64 k/ft/lane and two 25k/lane four feet apart to represent a random cars moving on the bridge. During this load combination we do not account to any wind load.
Load combination two
The dead load with 1.25 factor represent the gravity load of the structure with safety factor. Load combination three
The other load combination we used is the earthquake load of 0.15 of Deal load.

Results:

Moving load deflection Figure. A
Moving load and dead load combination deflection Figure. B Dead load deflection Figure.C
The model deflection Figure. D

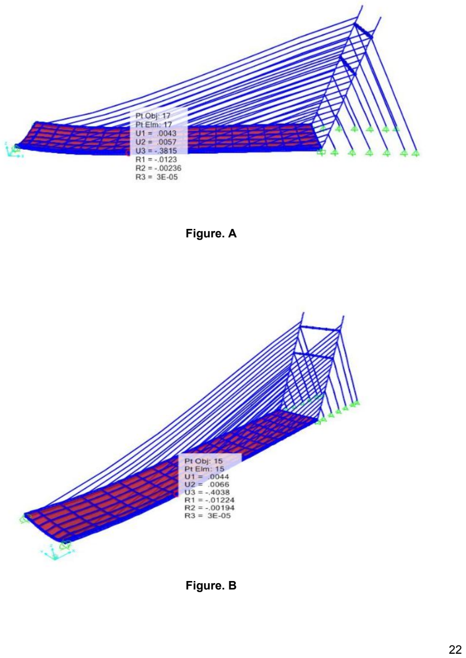
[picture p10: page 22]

Figure. A

Figure. B

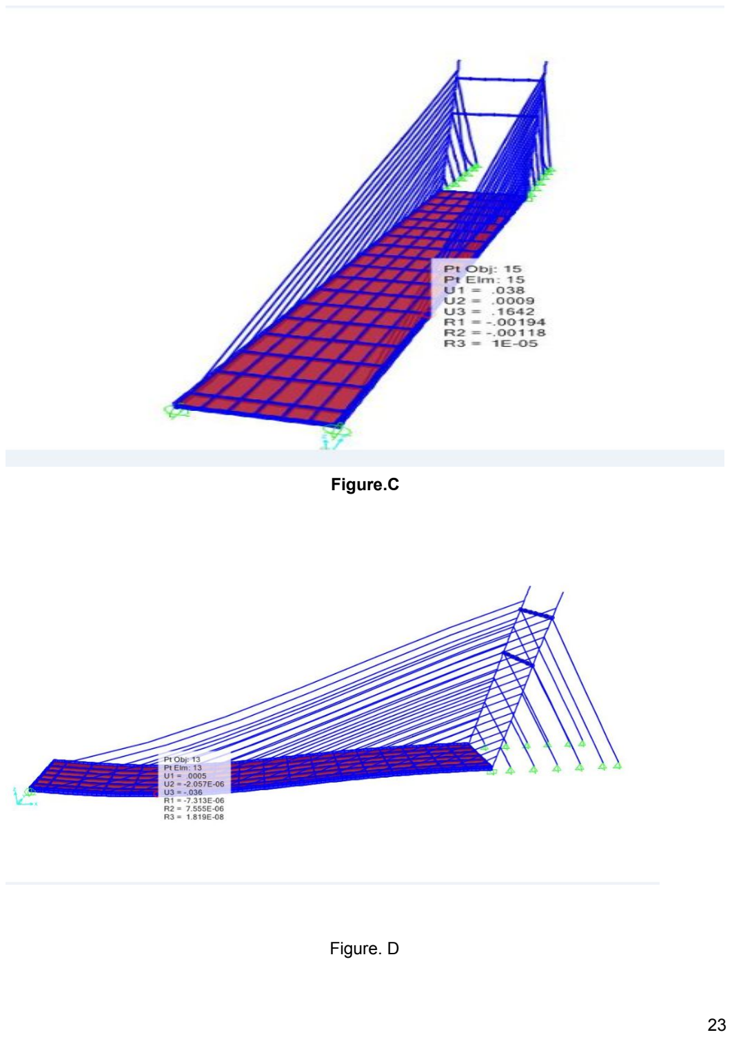
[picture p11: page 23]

Figure.C

Figure. D

The lane loads Figure.E

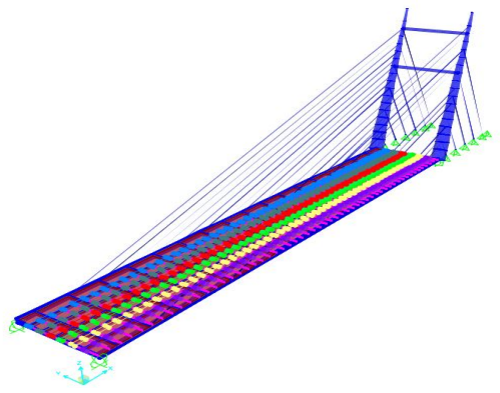
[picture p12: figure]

Figure. E

Constructability
The construction of the cable stay bridge.
Step one:
Construct the adequate foundations and the abutment Step two:
Construct the pylons
Step three:
Add the cable based on the deck constructions
Step four:
Add the deck sections of 60 ft long
The deck and cable construction will go hand by hand.
We recommended a use of cranes and ships to construct the deck which allow for minimum risk.

Design Drawings
Elevation view of proposed structure

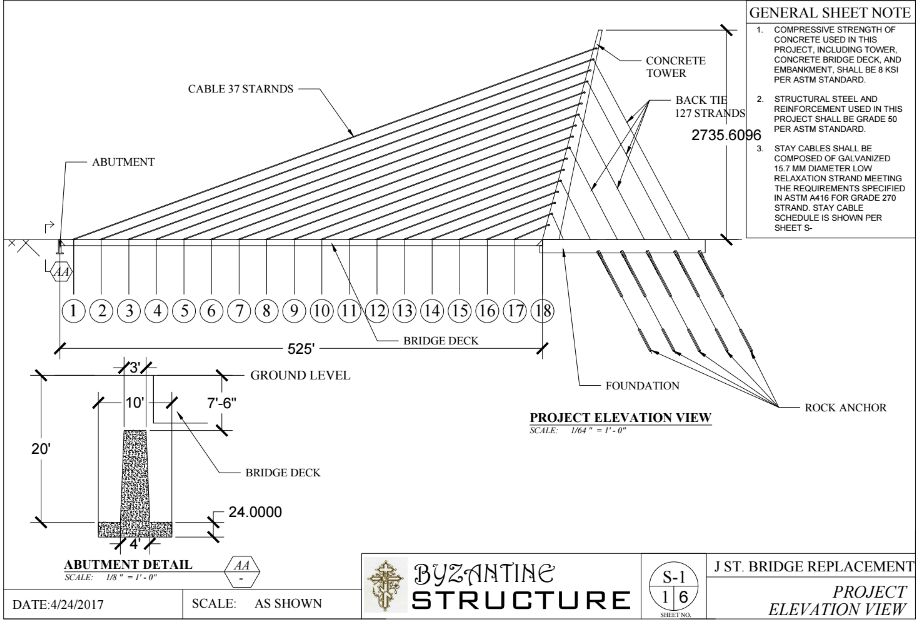
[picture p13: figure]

Plan view of proposed structure:

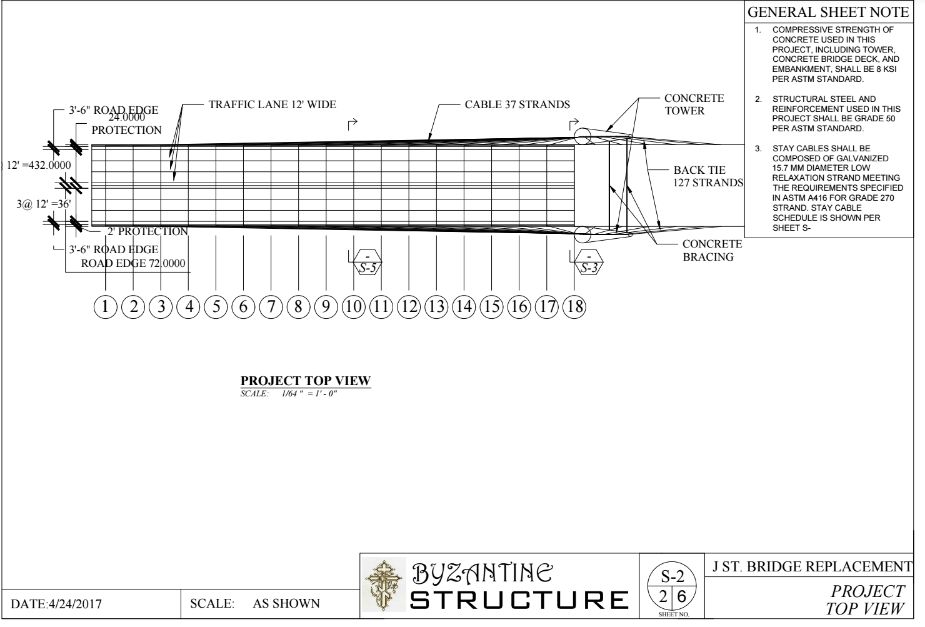
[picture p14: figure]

Tower Cross Section

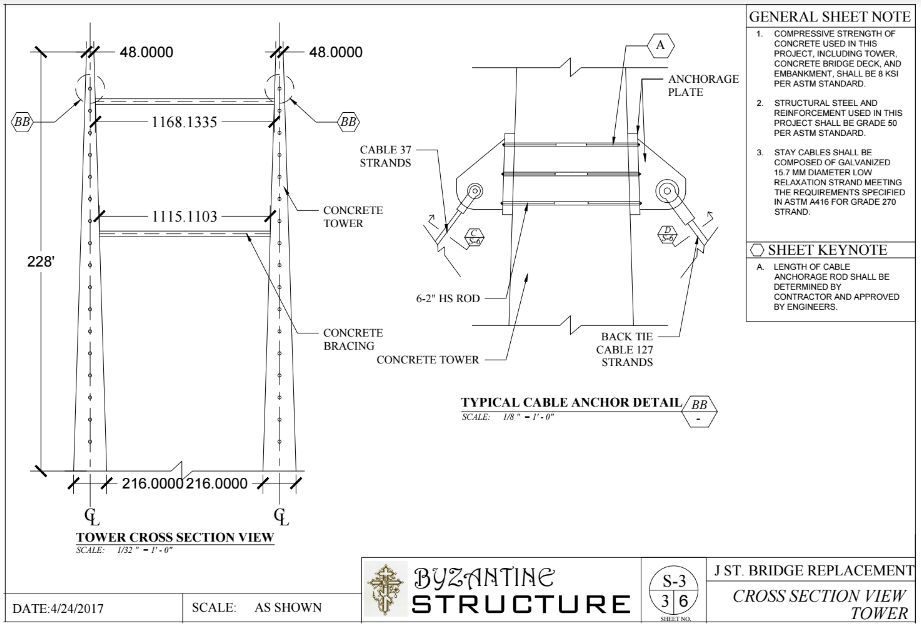
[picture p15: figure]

Bridge Deck Cross Section

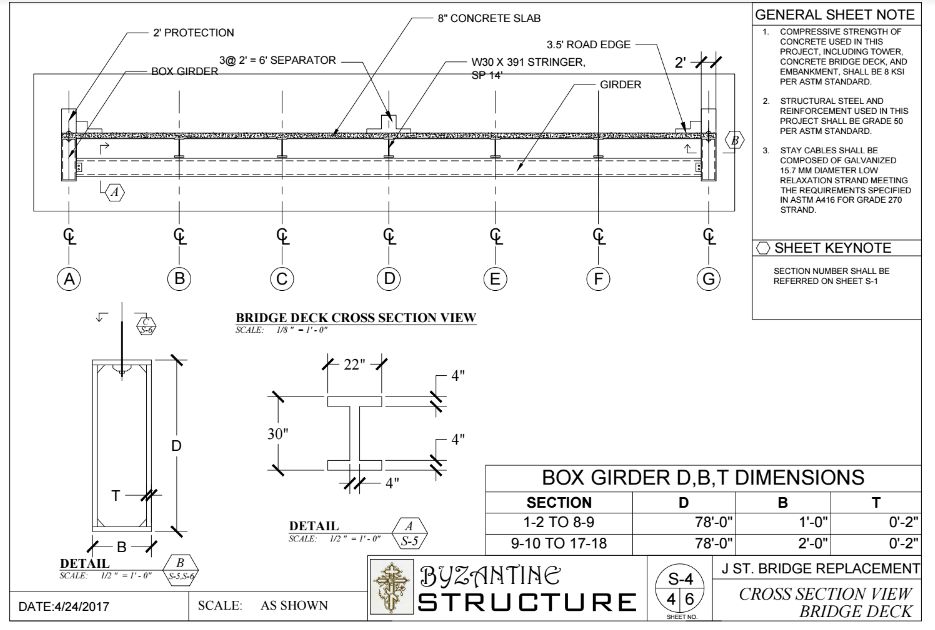
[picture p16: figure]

Bridge Framing Plan

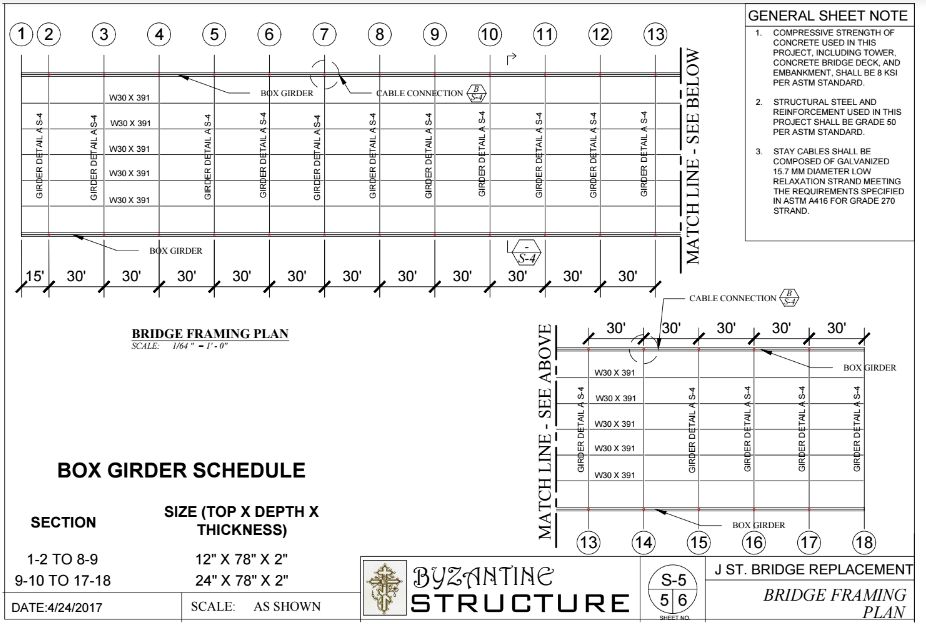
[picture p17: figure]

Cable

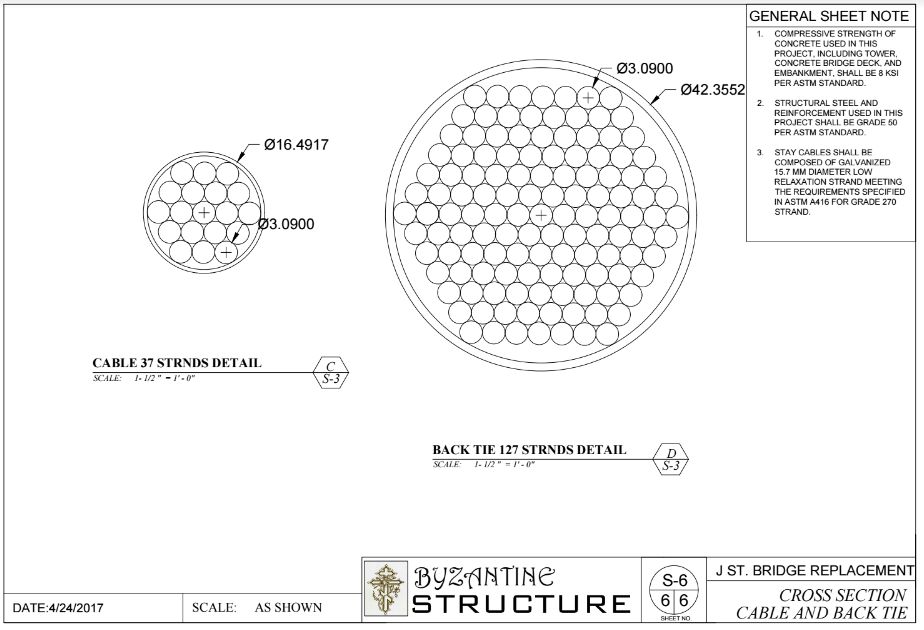
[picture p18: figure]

## IV. Appendix

Excel Load Calculations Sheet

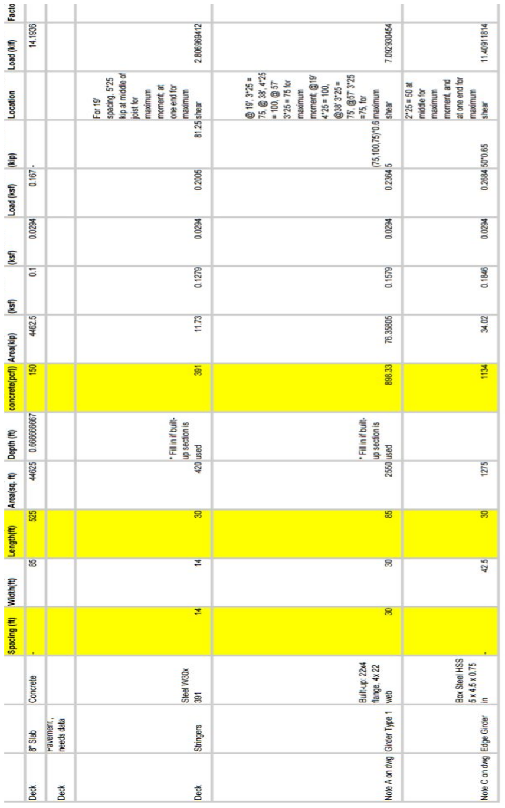
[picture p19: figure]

Matlab Codes and Design Tools Beam Capacity Check:
clear all; clc

Lb = 25*12;
E = 29000; Fy = 50;
A = 115; tf = 2.44; bf = 15.6; h = 26.5; tw = 1.36 ; d = 33.2; Cb = 1.14;

ry = 0; %% if do not know, ry = 0
rts = 0; %% if do not know, rts = 0
J = 0; %% if do not know, J = 0
Sx = 1250; %% if do not know, Sx = 0 Z = 0;

h0 = d-tf;

if ry==0
Iy = tf*bf^3/6;
ry = (Iy/A)^.5;
end

if J == 0;
J = 1/3*(bf*tf^3*2 + h*tw^3); end

if Sx == 0
y = (tf*2+h)/2;
Ix = (bf*tf^3*2 + tw*h^3)/12+ bf*tf*(y-tf/2)^2*2; Sx = Ix / y;
end

if rts ==0
Iy = tf*bf^3/6;
rts = (Iy*h0/2/Sx)^.5;
end

if Z == 0
y = (tf*2+h)/2;
Z = tf*bf*(y-tf/2)*2 + h/2*tw*h/4*2; end

Mp = Z * Fy;

%%%%%%%%%%%%%%%%%%%%%%%%%%%%%%%%%
Lp = 1.76*ry*(E/Fy)^.5;
Lr = 1.95*rts*E/(0.7*Fy)* (J/(Sx*h0)+((J/(Sx*h0))^2+6.76*(0.7*Fy/E)^2)^.5)^.5;

if Lb <= Lp
disp('case 1');
Mn = Mp;
elseif Lb <= Lr
Mn = Cb*(Mp - (Mp-0.7*Fy*Sx)*((Lb-Lp)/(Lr-Lp))) if Mn >= Mp
Mn = Mp;
end
disp('case 2');
else
Mn = Cb * Sx*pi^2*E/(Lb/rts)^2* (1+0.078*J/Sx/h0*(Lb/rts)^2)^.5 if Mn >= Mp
Mn = Mp;
end
disp('case 3');
end

disp('Mn in feet');
Mn = Mn /12
Mu = 0.9 * Mn

Lateral Buckling
clear all; clc
% require 7371
Lb = 85*12;
E = 29000; Fy = 50;
A = 376; tf = 2; bf = 24; tw = 4; d = 78; Cb = 1.14; h = d - 2*tf;
ry = 0; %% if do not know, ry = 0
rts = 0; %% if do not know, rts = 0
J = 0; %% if do not know, J = 0 Sx = 0; %% if do not know, Sx = 0 Z = 0;

h0 = d-tf;

if ry==0

Iy = tf*bf^3/6;
ry = (Iy/A)^.5;
end

if J == 0;
J = 1/3*(bf*tf^3*2 + h*tw^3); end

if Sx == 0
y = (tf*2+h)/2;
Ix = (bf*tf^3*2 + tw*h^3)/12+ bf*tf*(y-tf/2)^2*2; Sx = Ix / y;
end

if rts ==0
Iy = tf*bf^3/6;
rts = (Iy*h0/2/Sx)^.5;
end

if Z == 0
y = (tf*2+h)/2;
Z = tf*bf*(y-tf/2)*2 + h/2*tw*h/4*2; end

Mp = Z * Fy;

%%%%%%%%%%%%%%%%%%%%%%%%%%%%%%%%%
Lp = 1.76*ry*(E/Fy)^.5;
Lr = 1.95*rts*E/(0.7*Fy)* (J/(Sx*h0)+((J/(Sx*h0))^2+6.76*(0.7*Fy/E)^2)^.5)^.5;

if Lb <= Lp
disp('case 1');
Mn = Mp;
elseif Lb <= Lr
Mn = Cb*(Mp - (Mp-0.7*Fy*Sx)*((Lb-Lp)/(Lr-Lp))) if Mn >= Mp
Mn = Mp;
end
disp('case 2');
else
Mn = Cb * Sx*pi^2*E/(Lb/rts)^2* (1+0.078*J/Sx/h0*(Lb/rts)^2)^.5 if Mn >= Mp
Mn = Mp;

end
disp('case 3');
end

disp('Mn in feet');
Mn = Mn /12
Mu = 0.9 * Mn

Local Buckling Check
bf = 11.6; tf = 1.91;
z = 490; Fy = 50; Sx = 419; h = 15.5; tw = 1.06; E = 29000;

lam_pf = 0.38*(E/Fy)^0.5; lam_rf = (E/Fy)^0.5;

Mp = z* Fy
lamda = bf/2/tf;

if lamda <= lam_pf
Mn = Mp / 12
elseif lamda <= lam_rf
Mn = Mp - (Mp - 0.7*Fy*Sx)*((lamda-lam_pf)/(lam_rf-lam_pf)) / 12 else
kc = 4 / (h/tw)^0.5;
if kc < 0.35
kc = 0.35;
elseif kc> 0.76
kc = 0.76;
end
Mn = 0.9*E*kc*Sx / lamda^2 / 12 end

Overall Buckling
clear all; clc;

Kx = [1.0];
Ky = [1.0];
L = [89*12];
rx = 12; ry = 12;
E = 3600; Fy = 6; Ag = 12.57*144;

KL_r = max([Kx.*L/rx; Ky.*L/ry]);

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
2; for i = 1:numel(KL_r) if KL_r(i) <= 4.71*(E/

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
y; elseFcr(i) = .877*Fe(i); end

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
klin

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
all; clc; Kx = [1.2 2 2

2

]; Ky = [.8 1 1 1]; L = [144 17*12+

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
]; rx = 5.51; ry = 3.13; E = 29000; Fy = 50; Ag = 35.2; KL_r = max([Kx.*L/rx; Ky.*L/ry]) Fe = pi^2*E./(KL_r).^2; for i = 1:numel(KL_r) if KL_r(i) <= 4.71*(E/Fy)^.5 Fcr(i) = 0.658^(Fy/Fe(i)) * F

y; elseFcr(i) = .877*Fe(i); end

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
al it

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
ol Pu = 0.9 * Fcr * Ag E=29000; %Specify Elastic Modulus Fy=50; %Specify Fy d=40;%specify depth in inches tf=2.5;%specify flange thickness in inc

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
cify

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
e in in

c

h

e

s
t

w

=

2.5;%

s

p

e

cify

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
b in in

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
2; d1=d-tf/2; | 3

d2=bf/2;
A1=2*bf*tf;
A2=4*(h/2)*tw;
%Check Local buckling of Compression Flange lambda=bf/tf;
lambdapf=1.12*sqrt((E/Fy));
lambdarf=1.4*sqrt(E/Fy);

% Variables
Ixx=2*bf*(tf^3)/12 +bf*tf*(bf/2-tf)+2*tw*(h^3)/12 +h*tw*(h/2-tw); %Check the d with yanlong for Ad^2
beff=1.92*tf*sqrt(E/Fy)*(1-(0.38/(bf/tf))*sqrt(E/Fy));
Seff=Ixx/beff;
Zx=0.25*(bf*((h+2*tw)^2)-(bf-2*tf)*h^2); %Z outer rectangle- Z inner rectangle Mp=Fy*Zx; %Mp=Fy*Zx
Sx=Ixx/(h/2-tf);
%Check for local buckling
if lambda<lambdapf
result='Section is Compact, No Local Buckling' Mn=Mp;
elseif lambda>lambdapf && lambda<lambdarf result='Inelastic Flange Local Buckling' Mn=Mp-(Mp-Fy*Sx)*(3.57*bf/tf)*(sqrt(Fy/E)-4.0); else
result='Inelastic Flange Local Buckling'
Mn=Fy*Seff;
end
Mn=num2str(0.9*Mn/12); %Mu in Kip foot, multiplied by safety factor 0.9 Mu=['Mu is ',Mn,' kipfoot']

Shear Checks
I_roll = 0; %% 1 if rolled I shape, 0 others
stiffen = 0; %% 0 if unstiffened, other 1
E = 29000; Fy = 50;
Cv = 0; %% initial
h = 26.5; tw = 1.36; bf = 15.6; tf = 2.44; %a = 25; % spacing

if h/tw <= 2.24*(E/Fy)^.5
phi = 1;
Cv = 1;
else
phi = 0.9;
end if h/tw < 260 && stiffen == 0 kv = 5;
else
kv = 5 + 5/(a/h)^2;
if a/h >3 || a/h > (260/(h/tw))^2 kv = 5;
end
end

if Cv == 1 || h/tw <= 1.1*(kv*E/Fy)^.5 Cv = 1;
elseif h/tw <= 1.37 * (kv*E/Fy)^.5 Cv = 1.1*(kv*E/Fy)^.5 / (h/tw); else
Cv = 1.51*E*kv / ((h/tw)^2*Fy); end

Aw = (h + 2*tf)*tw;
Vn = 0.6*Fy*Aw*Cv;
Vu = phi*Vn

%% check stiffened
J = 2.5 / (a/h)^2 -2;
Iww = a * tw^3* J

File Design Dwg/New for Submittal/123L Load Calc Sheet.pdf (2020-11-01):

Preliminary Bridge Load Calculation

Analyzed w/t Matlab
Data Output
Data to be filled in
Discarded Data
Load Combo | 1.2D +1.6L
| 1.4D

Tandom Point Load
2 x 25 kip @ 4 ft per lane Calculation sheet correction
Section | Structural Element
| | | Spacing (ft)
Deck | 8" Slab | Concrete | -
Deck | Pavement , needs data
Deck | Springers | Steel W30x 391 | 14
Note A on dwg Girder Type 1
| | flange, 6 x 48 | 30
Note B on dwg Girder Type 2 (Not Used) | Steel W30x261 | 19
Deck | Bottom Deck (Not Used) | in x 2.5 in | 12.5
Note C on dwg Edge Girder
| | x 4.5 x 0.75 in | 9.5

*HSS 40inx40in 2.5 in wall thickness works Mu=19800 k-ft, Code has been Uploade

Live Load Impact Factor
one 25 kip must be distributed to each edge girder | 0.65 for > = 3 lines
210
Tributary Area
Tributary Width(ft) | Tributary Length(ft) | Tributary Area(sq. ft) | Depth (ft)

Weight (plf
85 | 525 | 44625 | 0.666666667 | 150
14 | 25 | 350 | section is used | 391
30 | 76 | 2280 | section is used | 1211.39
19 | 25 | 475 | section is used | 261
12.5 | 85 | 1062.5 | section is used | 1276.041667
9.5 | 30 | 285 | | 574

ed -Sam

2.496 | I
Distributed Load | deflection
/Tribuary

(ksf)

(ksf)

Load (ksf)

(kip) | Tandom Load Location
4462.5 | 0.1000 | 0.0294 | 0.1670 -
9.775 | 0.1279 | 0.0294 | 0.2005 | 81.25

middle of joist for maximum
92.06564 | 0.1404 | 0.0294 | 0.2154 (75,100,75)*0.65

4*25 = 100, @ 57' 3*25 =
6.525 | 0.1137 | 0.0294 | 0.1835
108.4635417 | 0.2699 | 0.0294 | 0.3779
17.2265625 | 0.1604 | 0.0294 | 0.2395 50*0.65

maximum moment, and at

| | | 20.35889605 | 610.7668816
| | | | 947.5609407

cable

106.6666667 | 17.5
0.000521049 | 18 | | | Service Load
Distributed | Multiplication | Multiplication
Weight(kip) | Moment (k-ft) Shear (kip)
14.1936 | 1 | 1 | 4462.5
2.806969412 | 21 | 5 | 1026.375 | 1234.92 | 116.34
6.463173882 | 1 | 17.5 | 1611.1487 | 7445.16 | 330.91
3.485887059 | 21 | 2 | 274.05 | 272.33 | 43.57
4.723891974 | 1 | 42 | 4555.47 | 3185.10 | 83.97
2.275406029 | 17.5 | 2 | 602.93 | -177.77 | 415.04
| | | new moment | 255.9831783
(kip) | 11506.09714
kip) | 0.2578
Live Load(kip) | 1310.4 Live Load | 0.0294
Total Load (kip) | 16108.54 Total Load Combo | 0.3610

Plus Tandom Load
460.2438855 508.9938855

Total Loading

Design Load
| Moment | | Shear
(kip)
| Capacity (k-ft)
Moment | Sufficent? | Capacity(kip) | Sufficent?
5026.3 | 6041.7 Yes | 1280.3 Yes
- | 8700 | 20000 Yes | 1280.3 Yes
- | 3184 | 3929 Yes | 831 Yes
- | - | 19804 Yes | - | Yes
24162.80399 | | 11907 Yes | - | Yes

= 10415/525/85
=L20
Combo (ksf) =

Axial
Axial Capacity (

263300 Yes

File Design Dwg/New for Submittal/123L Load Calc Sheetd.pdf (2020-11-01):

Preliminary Bridge Load Calculation

Analyzed w/t Matlab
Data Output
Data to be filled in
Discarded Data

Load Combo 1.2D +1.6L
1.4D
Tandom Point Load | Live Load Impact Factor
2 x 25 kip @ 4 ft per lane | one 25 kip must be distributed to each edge girder | 0.65 for > = 3 lines | 2.496 | I | 106.6666667 | 17.5
Calculation sheet correction | 210 | Design Load
Section | Structural Element | Tributary Area | Distributed Load | deflection | 0.000521049 | 18 | Service Load | Moment | Shear
Spacing (ft) | Tributary Width(ft) | Tributary Length(ft) Tributary Area(sq. ft) | Depth (ft)

Weight (plf

g
/Tribuary

(ksf)

(ksf)

Load (ksf)

(kip) | Tandom Load Location | Distributed

g
| | | | | | | Multiplication | Multiplication | Weight(kip) | Moment (k-ft) | Shear (kip)

p
(kip)

Capacity (k-ft)

g
Moment | Sufficent? | Capacity(kip) | Sufficent?
Deck | 8" Slab | Concrete | - | 85 | 525 | 44625 | 0.666666667 | 150 | 4462.5 | 0.1000 | 0.0294 | 0.1670 - | 14.1936 | 1 | 1 | 4462.5
Deck | Pavement , needs data
Deck | Springers | Steel W30x 391 | 14 | 14 | 25 | 350

p
section is used | 391 | 9.775 | 0.1279 | 0.0294 | 0.2005 | 81.25
p | g, | p
middle of joist for maximum | 2.806969412 | 21 | 5 | 1026.375 | 1234.92 | 116.34 | 5026.3 | 6041.7 | Yes | 1280.3 | Yes
Note A on dwg | Girder Type 1

p
flange, 6 x 48 | 30 | 30 | 76 | 2280

p
section is used | 1211.39 | 92.06564 | 0.1404 | 0.0294 | 0.2154 (75,100,75)*0.65
@ , | , @ ,
4*25 = 100, @ 57' 3*25 = | 6.463173882 | 1 | 17.5 | 1611.1487 | 7445.16 | 330.91 | - | 8700 | 20000 | Yes | 1280.3 | Yes
Note B on dwg | Girder Type 2 (Not Used) | Steel W30x261 | 19 | 19 | 25 | 475

p
section is used | 261 | 6.525 | 0.1137 | 0.0294 | 0.1835 | 3.485887059 | 21 | 2 | 274.05 | 272.33 | 43.57 | - | 3184 | 3929 | Yes | 831 | Yes
Deck | Bottom Deck (Not Used)
in x 2.5 in | 12.5 | 12.5 | 85 | 1062.5

p
section is used | 1276.041667 | 108.4635417 | 0.2699 | 0.0294 | 0.3779 | 4.723891974 | 1 | 42 | 4555.47 | 3185.10 | 83.97 | - | - | 19804 | Yes | - | Yes
Note C on dwg | Edge Girder
x 4.5 x 0.75 in | 9.5 | 9.5 | 30 | 285 | 574 | 17.2265625 | 0.1604 | 0.0294 | 0.2395 50*0.65
maximum moment, and at | 2.275406029 | 17.5 | 2 | 602.93 | -177.77 | 415.04 | 24162.80399 | 11907 | Yes | - | Yes
| | | | | | | | | new moment | 255.9831783
20.35889605 | 610.7668816

g
(kip) | 11506.09714
| | | | | | | | | | (
kip) | 0.2578

( )
| | | | | | | | | | | | = 10415/525/85
Live Load(kip) | 1310.4 Live Load | 0.0294

( )
=L20
947.5609407
(kip) | 16108.54 Total Load Combo | 0.3610
| | | | | | | | | | | | Combo (ksf) =

*HSS 40inx40in 2.5 in wall thickness works Mu=19800 k-ft, Code has been Uploaded -Sam

Total Loading

Axial
Axial Capacity (

263300 Yes

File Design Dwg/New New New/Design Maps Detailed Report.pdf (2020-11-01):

3/28/2015 | Design Maps Detailed Report
http://ehp4-earthquake.cr.usgs.gov/designmaps/us/report.php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… | 1/6

From Figure 22-1 (http://earthquake.usgs.gov/hazards/designmaps/downloads/pdfs/2010_ASCE-7_Figure_22-1.pdf)
[1]

From Figure 22-2 (http://earthquake.usgs.gov/hazards/designmaps/downloads/pdfs/2010_ASCE-7_Figure_22-2.pdf)
[2]

## Design Maps Detailed Report

### ASCE 7-10 Standard (37.87293°N, 122.25708°W)

Site Class C – “Very Dense Soil and Soft Rock”, Risk Category I/II/III

### Section 11.4.1 — Mapped Acceleration Parameters

Note: Ground motion values provided below are for the direction of maximum horizontal spectral response acceleration. They have been converted from corresponding geometric mean ground motions computed by the USGS by applying factors of 1.1 (to obtain SS) and 1.3 (to obtain S1). Maps in the 2010 ASCE-7 Standard are provided for Site Class B. Adjustments for other Site Classes are made, as needed, in Section 11.4.3.

SS = 2.464 g

S1 = 1.024 g

### Section 11.4.2 — Site Class

The authority having jurisdiction (not the USGS), sitespecific geotechnical data, and/or the default has classified the site as Site Class C, based on the site soil properties in accordance with Chapter 20.

Table 20.3–1 Site Classification

Site Class | vS | N or Nch | su
A. Hard Rock | >5,000 ft/s | N/A | N/A
B. Rock | 2,500 to 5,000 ft/s | N/A | N/A
C. Very dense soil and soft rock | 1,200 to 2,500 ft/s | >50 | >2,000 psf
D. Stiff Soil | 600 to 1,200 ft/s | 15 to 50 | 1,000 to 2,000 psf
E. Soft clay soil | <600 ft/s | <15 | <1,000 psf
Any profile with more than 10 ft of soil having the
| characteristics:
Plasticity index PI > 20,
Moisture content w ≥ 40%, and Undrained shear strength su < 500 psf
F. Soils requiring site response
analysis in accordance with Section
21.1 | | See Section 20.3.1

For SI: 1ft/s = 0.3048 m/s 1lb/ft² = 0.0479 kN/m² http://ehp4-earthquake.cr.usgs.gov/designmaps/us/report.php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… 2/6

### Section 11.4.3 — Site Coefficients and Risk–Targeted Maximum Considered Earthquake (MCER) Spectral Response Acceleration Parameters

Table 11.4–1: Site Coefficient Fa

Site Class | Mapped MCE R Spectral Response Acceleration Parameter at Short Period
SS ≤ 0.25 | SS = 0.50 | SS = 0.75 | SS = 1.00 | SS ≥ 1.25
A | 0.8 | 0.8 | 0.8 | 0.8 | 0.8
B | 1.0 | 1.0 | 1.0 | 1.0 | 1.0
C | 1.2 | 1.2 | 1.1 | 1.0 | 1.0
D | 1.6 | 1.4 | 1.2 | 1.1 | 1.0
E | 2.5 | 1.7 | 1.2 | 0.9 | 0.9
F | See Section 11.4.7 of ASCE 7

Note: Use straight–line interpolation for intermediate values of SS

For Site Class = C and SS = 2.464 g, Fa = 1.000

Table 11.4–2: Site Coefficient Fv

Site Class | Mapped MCE R Spectral Response Acceleration Parameter at 1–s Period
S1 ≤ 0.10 | S1 = 0.20 | S1 = 0.30 | S1 = 0.40 | S1 ≥ 0.50
A | 0.8 | 0.8 | 0.8 | 0.8 | 0.8
B | 1.0 | 1.0 | 1.0 | 1.0 | 1.0
C | 1.7 | 1.6 | 1.5 | 1.4 | 1.3
D | 2.4 | 2.0 | 1.8 | 1.6 | 1.5
E | 3.5 | 3.2 | 2.8 | 2.4 | 2.4
F | See Section 11.4.7 of ASCE 7

Note: Use straight–line interpolation for intermediate values of S1

For Site Class = C and S1 = 1.024 g, Fv = 1.300

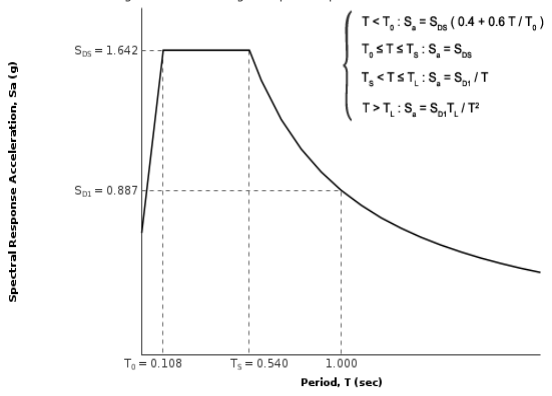
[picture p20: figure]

http://ehp4-earthquake.cr.usgs.gov/designmaps/us/report.php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… 3/6

Equation (11.4–1):

Equation (11.4–2):

Equation (11.4–3):

Equation (11.4–4):

From Figure 22-12 (http://earthquake.usgs.gov/hazards/designmaps/downloads/pdfs/2010_ASCE-7_Figure_22-12.pdf)
[3]

SMS = FaSS = 1.000 x 2.464 = 2.464 g

SM1 = FvS1 = 1.300 x 1.024 = 1.331 g

### Section 11.4.4 — Design Spectral Acceleration Parameters

SDS = ⅔ SMS = ⅔ x 2.464 = 1.642 g

SD1 = ⅔ SM1 = ⅔ x 1.331 = 0.887 g

### Section 11.4.5 — Design Response Spectrum

TL = 8 seconds

Figure 11.4–1: Design Response Spectrum

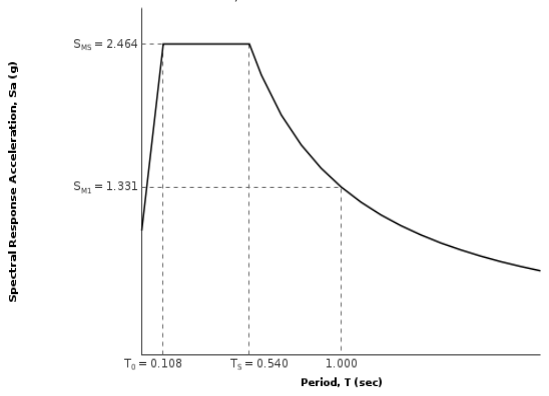
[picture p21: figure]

http://ehp4-earthquake.cr.usgs.gov/designmaps/us/report.php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… 4/6

### Section 11.4.6 — Risk-Targeted Maximum Considered Earthquake (MCER) Response Spectrum

The MCER Response Spectrum is determined by multiplying the design response spectrum above
by 1.5.

http://ehp4-earthquake.cr.usgs.gov/designmaps/us/report.php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… 5/6

From Figure 22-7 (http://earthquake.usgs.gov/hazards/designmaps/downloads/pdfs/2010_ASCE-7_Figure_22-7.pdf)
[4]

Equation (11.8–1):

From Figure 22-17 (http://earthquake.usgs.gov/hazards/designmaps/downloads/pdfs/2010_ASCE-7_Figure_22-17.pdf)
[5]

From Figure 22-18 (http://earthquake.usgs.gov/hazards/designmaps/downloads/pdfs/2010_ASCE-7_Figure_22-18.pdf)
[6]

### Section 11.8.3 — Additional Geotechnical Investigation Report Requirements for Seismic Design Categories D through F

PGA = 0.953

PGAM = FPGAPGA = 1.000 x 0.953 = 0.953 g

Table 11.8–1: Site Coefficient FPGA

Site Class | Mapped MCE Geometric Mean Peak Ground Acceleration, PGA
PGA ≤ 0.10 | PGA = 0.20 | PGA = 0.30 | PGA = 0.40 | PGA ≥ 0.50
A | 0.8 | 0.8 | 0.8 | 0.8 | 0.8
B | 1.0 | 1.0 | 1.0 | 1.0 | 1.0
C | 1.2 | 1.2 | 1.1 | 1.0 | 1.0
D | 1.6 | 1.4 | 1.2 | 1.1 | 1.0
E | 2.5 | 1.7 | 1.2 | 0.9 | 0.9
F | See Section 11.4.7 of ASCE 7

Note: Use straight–line interpolation for intermediate values of PGA

For Site Class = C and PGA = 0.953 g, FPGA = 1.000

### Section 21.2.1.1 — Method 1 (from Chapter 21 – Site-Specific Ground Motion Procedures for Seismic Design)

CRS = 1.002

CR1 = 0.978 http://ehp4-earthquake.cr.usgs.gov/designmaps/us/report.php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… 6/6

### Section 11.6 — Seismic Design Category

Table 11.6-1 Seismic Design Category Based on Short Period Response Acceleration Parameter
VALUE OF SDS | RISK CATEGORY
I or II | III | IV
SDS < 0.167g | A | A | A
0.167g ≤ SDS < 0.33g | B | B | C
0.33g ≤ SDS < 0.50g | C | C | D
0.50g ≤ SDS | D | D | D

For Risk Category = I and SDS = 1.642 g, Seismic Design Category = D

Table 11.6-2 Seismic Design Category Based on 1-S Period Response Acceleration Parameter
VALUE OF SD1 | RISK CATEGORY
I or II | III | IV
SD1 < 0.067g | A | A | A
0.067g ≤ SD1 < 0.133g | B | B | C
0.133g ≤ SD1 < 0.20g | C | C | D
0.20g ≤ SD1 | D | D | D

For Risk Category = I and SD1 = 0.887 g, Seismic Design Category = D

Note: When S1

is greater than or equal to 0.75g, the Seismic Design Category is E for buildings in Risk Categories I, II, and III, and F for those in Risk Category IV, irrespective of
the above.

Seismic Design Category ≡ “the more severe design category in accordance with Table 11.6-1 or 11.6-2” = E

Note: See Section 11.6 for alternative approaches to calculating Seismic Design Category.

### References

1. Figure 22-1: http://earthquake.usgs.gov/hazards/designmaps/downloads/pdfs/2010_ASCE-7_Figure_22-1.pdf
2. Figure 22-2: http://earthquake.usgs.gov/hazards/designmaps/downloads/pdfs/2010_ASCE-7_Figure_22-2.pdf
3. Figure 22-12: http://earthquake.usgs.gov/hazards/designmaps/downloads/pdfs/2010_ASCE-7_Figure_22- 12.pdf
4. Figure 22-7: http://earthquake.usgs.gov/hazards/designmaps/downloads/pdfs/2010_ASCE-7_Figure_22-7.pdf
5. Figure 22-17: http://earthquake.usgs.gov/hazards/designmaps/downloads/pdfs/2010_ASCE-7_Figure_22- 17.pdf
6. Figure 22-18: http://earthquake.usgs.gov/hazards/designmaps/downloads/pdfs/2010_ASCE-7_Figure_22- 18.pdf

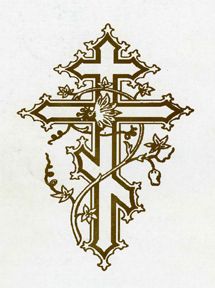
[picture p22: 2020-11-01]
Design Dwg/Design Drawings 4-24 Leigh Anne/cross.jpg

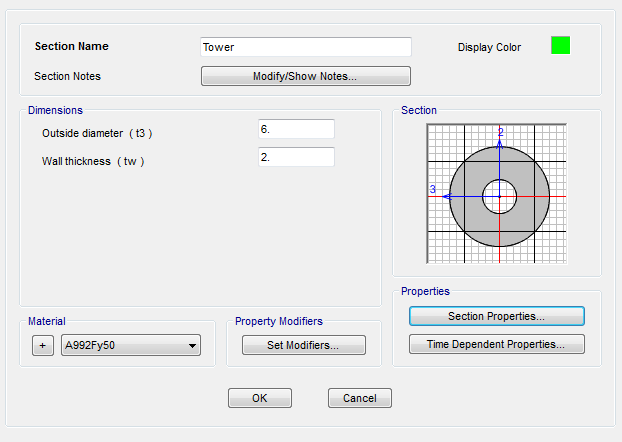
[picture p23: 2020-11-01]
Design Dwg/New New New/Tower_new.PNG

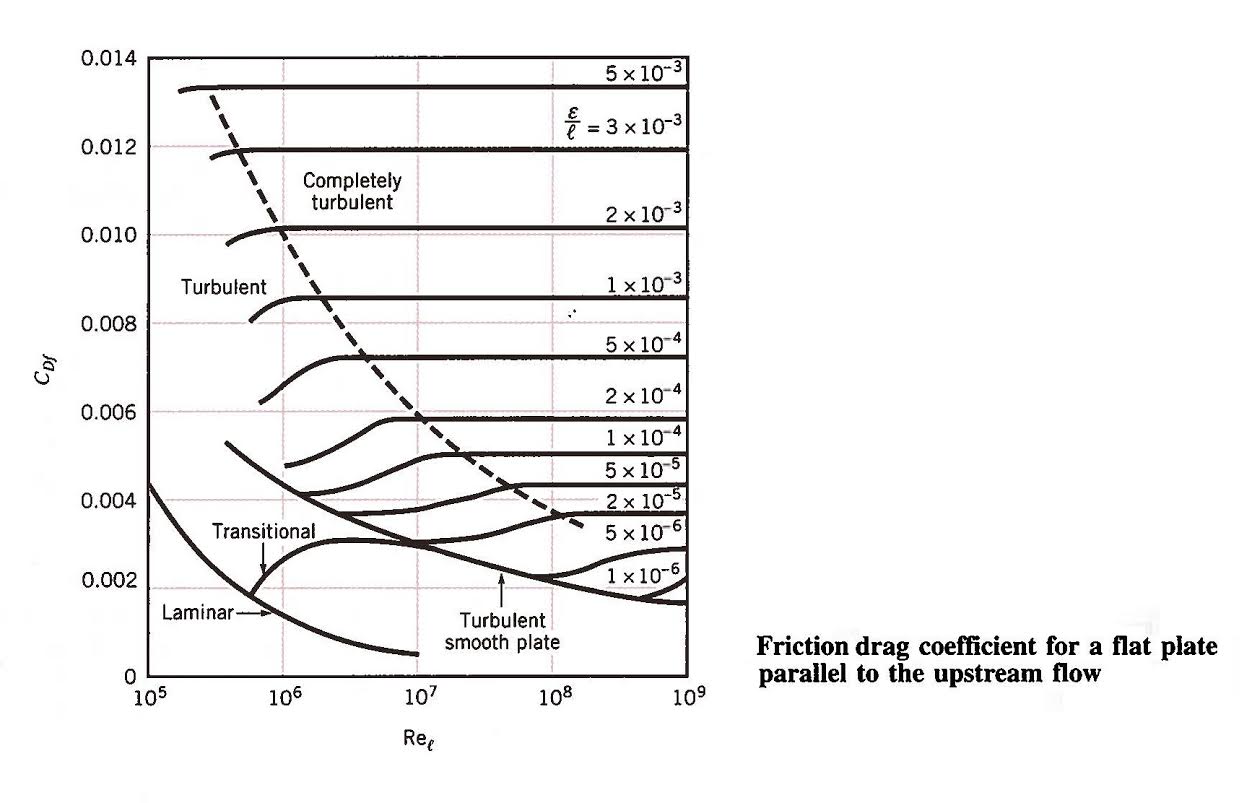
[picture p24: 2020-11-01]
Design Dwg/New New New/unnamed.jpg

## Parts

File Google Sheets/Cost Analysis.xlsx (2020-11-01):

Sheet: Sheet2
Cost
Material | Unit price | In Units Of | Unit (LB or CF) | Material Cost
Furnish Structural Steel | 4 | $ / LB | 3544486.85 | $14177947.40
Erect Structural Steel | 5 | $ / LB | 3544486.85 | $17722434.25
Furnish Cable System | 4.5 | $ / LB | 309188.5828 | $1391348.62
Erect Cable System | 6 | $ / LB | 309188.5828 | $1855131.50
Bar Reinforcement Steel | 6 | $ / LB | 2115725.779 | $12694354.67
Structural Concrete | 30 | $ / CF | 215890.3856 | $6476711.57
 |  |  |  | $54317928.01
 |  |  |  | Total Cost
Cable
Cable # | Length (ft) | # of Strands | Cable Diameter(mm) | Cable diameter (ft) | Volume of cable (cubic feet) | Density (pcf) | Weight (LB)
1 | 602.7589204 | 37 | 109.9 | 0.3605643 | 61.5458267 | 374 | 23018.13919
2 | 567.4429176 | 37 | 109.9 | 0.3605643 | 57.9398202 | 374 | 21669.49275
3 | 532.126994 | 37 | 109.9 | 0.3605643 | 54.33382177 | 374 | 20320.84934
4 | 496.8111663 | 37 | 109.9 | 0.3605643 | 50.72783315 | 374 | 18972.2096
5 | 461.4954567 | 37 | 109.9 | 0.3605643 | 47.12185658 | 374 | 17623.57436
6 | 426.1798944 | 37 | 109.9 | 0.3605643 | 43.51589506 | 374 | 16274.94475
7 | 390.8645195 | 37 | 109.9 | 0.3605643 | 39.90995266 | 374 | 14926.32229
8 | 355.5493876 | 37 | 109.9 | 0.3605643 | 36.30403509 | 374 | 13577.70912
9 | 320.2345794 | 37 | 109.9 | 0.3605643 | 32.69815055 | 374 | 12229.10831
10 | 284.920215 | 37 | 109.9 | 0.3605643 | 29.09231135 | 374 | 10880.52444
11 | 249.606483 | 37 | 109.9 | 0.3605643 | 25.4865367 | 374 | 9531.964725
12 | 214.2936958 | 37 | 109.9 | 0.3605643 | 21.88085853 | 374 | 8183.441089
13 | 178.9824127 | 37 | 109.9 | 0.3605643 | 18.27533394 | 374 | 6834.974894
14 | 143.6737429 | 37 | 109.9 | 0.3605643 | 14.67007618 | 374 | 5486.608491
15 | 108.3702405 | 37 | 109.9 | 0.3605643 | 11.06534605 | 374 | 4138.439423
16 | 73.07939487 | 37 | 109.9 | 0.3605643 | 7.461908268 | 374 | 2790.753692
17 | 37.8366383 | 37 | 109.9 | 0.3605643 | 3.863380707 | 374 | 1444.904384
18 | 235 | 127 | 204.1 | 0.6696194 | 82.75865648 | 374 | 30951.73752
19 | 194.5 | 127 | 204.1 | 0.6696194 | 68.4959944 | 374 | 25617.50191
20 | 154 | 127 | 204.1 | 0.6696194 | 54.23333233 | 374 | 20283.26629
21 | 113 | 127 | 204.1 | 0.6696194 | 39.79458801 | 374 | 14883.17592
22 | 72.5 | 127 | 204.1 | 0.6696194 | 25.53192593 | 374 | 9548.9403
 |  |  |  |  |  |  | 309188.5828
 |  |  |  |  |  |  | Total Cost
Deck Materials
 |  |  | Total Self Weight(kip) | Concrete in CF
Deck | 8" Slab | Concrete | 4462.5 | 29750
Deck | Pavement , needs data
Deck | Stringers | Steel W30x 391 | 1055.7 | .
Note A on dwg | Girder Type 1 | Built-up: 18x4 flange, 3 x 32 web | 1298.08685
Note B on dwg | Girder Type 2 (Not Used) | Steel W30x261 | 0
Deck | Bottom Deck (Not Used) | Steel 40 in x 40 in x 2.5 in | 0
Note C on dwg | Edge Girder | Box Steel HSS 5 x 4.5 x 0.75 in | 1190.7
Tower Materials
Tower diameter 1 | 3 | ft
Tower diameter 2 | 18 | ft
Tower Height | 228 | ft
Tower Volume | 92400.44508 | ft^3
Two Towers | 184800.8902 | ft^3
Tower beam 1 | 689.1863063 | ft^3
Tower beam 2 | 650.30913 | ft^3

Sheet: Sheet1
 | Project Name: | Byzantine Steel Bridge
 | Location: | Sacramento, Ca
 | Line Number | Description | Quantity | Unit | Material Costs($) | Labor Costs ($) | Equipment Costs ($) | Subcontract ($) | Estimate Total ($)
Framing |  | Built up plate girders | 1 | Ton | 3125 | 605 | 177 |  | 3907
 |  | Box Girders (35-50') | 1 |  |  |  |  |  | 0
 |  | Continuous Fillet Welds, including equipment- 8-11 passes 1" thick, 2.4#/LF | 1 | Linear foot | 5.2 | 69.5 | 24 |  | 98.7
 |  | Weld shear connectors 0.75" diameter, 6-3/16" long | 1 | Each | 0.77 | 0.9 | 0.52 |  | 2.19
 |  | Bolts |  | Each
 |  | Vibration and bearing pads- 1" thick laminated synthetic rubber impregnated cotton duck | 1 | Square foot | 130 | 40 | 0 |  | 170
 |  | Compression seals (for expansion joints)
 |  | Seal galvanization
 |  | Approach railings |  | Linear foot
 |  | Cable |  | Linear foot
 |  | Shear stud (Spacing=8in along length of bridge, 6in width)
Concrete |  | Grout | 1 | Cubic Feet | 376 | 245 |  |  | 621
Asphalt/ Road |  | Graded friction course
 |  | Base Courses
 |  | Drainage Layers
 |  | Road markings
 |  | Griders
 |  | Beams
 |  | Concrete deck
 |  | Concrete Pylon
 | Do we need these? | 5% steel weight added for bolts
 | Remove? | shear studs
 |  | 2 box girders
 |  | rebar weights
 |  | abutment wieght
 |  | rock anchors
 |  | cable lengths and weights
 |  | barriers

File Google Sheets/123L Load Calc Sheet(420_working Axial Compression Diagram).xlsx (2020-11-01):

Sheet: Calculation Main
Preliminary Bridge Load Calculation
 | Analyzed w/t Matlab
 | Data Output
 | Data to be filled in
 | Discarded Data
Load Combo | 1.2D +1.6L
 | 1.4D
 |  | Tandom Point Load |  |  |  |  | Live Load Impact Factor
 |  | 2 x 25 kip @ 4 ft per lane |  | one 25 kip must be distributed to each edge girder |  |  | 0.65 | for > = 3 lines |  |  |  | 2.496 |  | I | 106.6666667 | 17.5
Calculation sheet correction |  |  |  |  | 210 |  |  |  |  |  |  |  |  |  |  |  |  |  |  |  |  | Design Load
Section | Structural Element |  |  | Tributary Area |  |  |  |  |  | Distributed Load |  |  |  | deflection | 0.0005210485854 | 18 |  |  | Service Load |  |  | Moment |  |  | Shear |  | Axial
 |  |  | Spacing (ft) | Tributary Width(ft) | Tributary Length(ft) | Tributary Area(sq. ft) | Depth (ft) | Material Unit Weight (plf except concrete(pcf)) | Self Weight /Tribuary Area(kip) | Dead Load (ksf) | Live Load (ksf) | Total Service Load (ksf) | Tandom Load (kip) | Tandom Load Location | Converted Distributed Load (klf) | Length Multiplication Factor | Width Multiplication Factor | Total Self Weight(kip) | Maximum Moment (k-ft) | Maximum Shear (kip) | Compression (kip) | LTB Moment Capacity (k-ft) | Local Buckling Moment Capacity (k-ft) | Sufficent? | Shear Capacity(kip) | Sufficent? | Axial Capacity (
Deck | 8" Slab | Concrete | - | 85 | 525 | 44625 | 0.6666666667 | 150 | 4462.5 | 0.1000 | 0.0294 | 0.1670 | - |  | 14.1936 | 1 | 1 | 4462.5
Deck | Pavement , needs data
Deck | Stringers | Steel W30x 391 | 14 | 14 | 25 | 350 | * Fill in if built-up section is used | 391 | 9.775 | 0.1279 | 0.0294 | 0.2005 | 81.25 | For 19' spacing, 5*25 kip at middle of joist for maximum moment; at one end for maximum shear | 2.806969412 | 21 | 5 | 1026.375 | 1234.92 | 116.34 |  | 5026.3 | 6041.7 | Yes | 1280.3 | Yes
Note A on dwg | Girder Type 1 | Built-up: 12 x 2 flange, 6 x 48 web | 30 | 30 | 76 | 2280 | * Fill in if built-up section is used | 857.5 | 65.17 | 0.1286 | 0.0294 | 0.2013 | (75,100,75)*0.65 | @ 19', 3*25 = 75, @ 38', 4*25 = 100, @ 57' 3*25 = 75 for maximum moment; @19' 4*25 = 100, @38' 3*25 = 75', @57' 3*25 =75, for maximum shear | 6.038505882 | 1 | 17.5 | 1140.475 | 7138.55 | 314.78 | - | 8700 | 20000 | Yes | 1280.3 | Yes
Note B on dwg | Girder Type 2 (Not Used) | Steel W30x261 | 19 | 19 | 25 | 475 | * Fill in if built-up section is used | 261 | 6.525 | 0.1137 | 0.0294 | 0.1835 |  |  | 3.485887059 | 21 | 2 | 0 | 272.33 | 43.57 | - | 3184 | 3929 | Yes | 831 | Yes
Deck | Bottom Deck (Not Used) | Steel 40 in x 40 in x 2.5 in | 12.5 | 12.5 | 85 | 1062.5 | * Fill in if built-up section is used | 1276.041667 | 108.4635417 | 0.2581 | 0.0294 | 0.3614 |  |  | 4.51745614 | 1 | 42 | 0.00 | 3043.10 | 81.31 | - | - | 19804 | Yes | - | Yes
Note C on dwg | Edge Girder | Box Steel HSS 5 x 4.5 x 0.75 in | 9.5 | 9.5 | 30 | 285 |  | 574.21875 | 17.2265625 | 0.1604 | 0.0294 | 0.2395 | 50*0.65 | 2*25 = 50 at middle for maximum moment, and at one end for maximum shear | 2.275406029 | 17.5 | 2 | 602.93 | 1872.09 | 398.91 | 16163.06344 |  | 11907 | Yes | - | Yes | 263300 | Yes
 |  |  |  |  |  |  |  |  |  |  |  |  |  |  |  |  |  | new moment | 255.9831783 |  |  |  |  |  | Allowable Deflection(in)
 |  |  |  |  |  |  |  |  |  |  |  | 20.35889605 | 610.7668816 |  |  | Total Loading | Dead Weight (kip) | 7232.279688 | Dead Load (in kip) | 0.1621 | Dead Load (ksf) = 10415/525/85 | P1 | 75.48132353 | not used | 26.7 | Dead
 |  |  |  |  |  |  |  |  |  |  |  |  |  |  |  |  | Live Load(kip) | 1310.4 | Live Load | 0.0294 | Live Load(ksf) =L20 | P2 | 43.57358824 | not used | 4.8 | Live
 |  |  |  |  |  |  |  |  |  |  |  |  | 633.845625 |  |  |  | Total Load (kip) | 10775.38 | Total Load Combo | 0.2415 | Total Load Combo (ksf) = Total Load/525/85 | Reaction Force | 163.9885962 | not used | 31.5 | Total
 |  |  |  |  |  |  |  |  |  |  |  |  |  |  |  |  |  | 633.845625
 |  |  |  |  |  |  |  |  |  |  |  |  |  |  |  |  |  | 126.769125 |  | 828.9596228
 | *HSS 40inx40in 2.5 in wall thickness works Mu=19800 k-ft, Code has been Uploaded -Sam |  |  |  |  |  |  |  |  |  |  |  |  |  |  |  |  | 1353.022658 |  |  |  |  |  | Tandom Load per Cable(Reducted )
 |  |  |  |  |  |  |  |  |  |  |  |  |  |  |  |  |  |  |  | Weight of Cable | 136.59 | kips |  | 97.5 | 8.125 | Moment of Reducted Tandom on Tower
 | Tower Size (Diameter) | 18 ft (bottom) |  | 3 ft (top) |  |  |  |  |  |  |  |  |  |  |  |  |  |  |  | Weight of Tower | 2086.65 | kips
 | Steel Ratio | 0.02 |  |  |  |  |  |  |  |  |  |  |  |  |  |  |  |  |  |  |  | x228/
 | Concrete Material | 6 ksi |  |  |  |  |  |  |  |  |  |  |  |  |  |  |  |  | Calc for Cable | 10.2622625 | 25.65565625 | 731.1862031
 |  |  |  |  |  |  |  |  |  |  |  |  |  |  |  | Plus Tandom Load
 |  |  |  |  |  |  |  |  |  |  |  |  |  | cable | 307.867875 | 356.617875 |  |  | cable | 7972

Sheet: Factors
 | Dimensions |  |  |  |  | EQ load | WS |  | Steel
# Lanes | width(ft) | length (ft) |  |  |  | 15% | 50 psf
6 | 85 | 525
Reduction factors
 | Dynamic load allowance | Impact Factor |  |  |  | Steel section weights | Weights (k/ft)
 | Deck Joints-All Limit states | 0.75 |  |  |  | W30*261 | 0.261
 | Fatigue and Fracture Limit State | 0.15 |  |  |  | W30*391 | 0.391
 | All other limit State | 0.33 |  |  |  | W30*200 | 0.2
 | Live load reduction factor for all 6 lanes loaded simultaneously | 0.65 |  |  |  | L8*8*1.125 | 0.0569
Material Properties
 | Material | Rho(pcf)
 | Concrete | 150 |  |  |  |  |  |  | 32.8125
 | Steel | 490
Dead loads |  | Dimension
Material | Section | Structural Element | #/deck | total # | Width (ft) /* Tributary Width | Length(ft) | Volume(cu. ft) | Self Weight(kip) | Spacing (ft) | Tributary Area/ element(sq. ft) | Total Dead Load(kip) | Live Load(kip) | Total Load(kip) | Distributed Load(klp)
Concrete | Deck | 8" Slab | - | - | 85 | 525 | 29750 | 4462.5 | - | 12 ft / joist | 4462.5 | 2110.5 | 6573 | 12.5
 |  | Reinforcement (Note 1) | - | - | 85 | 525 | 595 | 291.55 | TBD | NA | 4754.05 | NA | 6864.55 | 13.1
Steel | Joists | W30*261 | 8 | 168 | 12 | 14 |  | 2411.64 | 12.5 | 175 | 26.9 | 2110.5 | 4522.53
 | Girders | W30*391 | 3 | 63 |  | 25 |  | 615.825 |  |  |  | 2110.5
 | Girders | W30*200 | 2 | 42 |  | 25 |  | 210 |  |  |  | 2110.5
 | Edge element | L8*8*1.125 | 2 | 42 |  | 25 |  | 59.745 |  |  |  | 2110.5
 | Total |  |  |  |  | 25 |  | 8051.26
Live loads | 0
Live load (k/f) | 3.9
Load Combinations | Kips |  |  |  |  |  |  |  |  | gider 1 | 744.7589412
1.2D+1.6L | 12937.512 |  |  |  |  |  |  |  |  | gider 2 | 1373.346912
1.4D | 11271.764 |  |  |  |  |  |  |  |  | gider 3 | 1364.431059
 |  |  |  |  |  |  |  |  |  | gider 4 | 1416.666176
 |  |  |  |  |  |  |  |  |  | gider 5 | 744.7589412
 |  |  |  | factor | reduction factor |  |  |  |  | gider 6 | 1373.346912
W14*159 | Joist | Dead | 1.159 | 1.2 | 0.65 |  |  |  |  | gider 7 | 1364.431059
 |  | Live | 5.43 | 1.6
 |  | Earthquake | 0.988 | 1
 |  | toal | 8.03 | klf | 2.3788 | only dead
 | girder | self dead | 2.12 klf
 |  | from joist (max) | 361.35 | 3 point load, one in middle
 |  | h | w | tf | tw |  | A
 |  | 96 | 48.7 | 4.2 | 2.5 | inches | 623.7
girder | Vmax | 211.8 | kips-ft
 | Mmax | 2448 | kips-ft
joist | Vmax | 60.225 | kips-ft
 | Mmax | 225.84375 | kips-ft

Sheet: Axial Force Diagram
Cable
 |  | Cable Design Tension (MT) (kip) |  |  |  | Cable Parameter
Cable # | Length (ft) | DL | LL(MAX) | LL(MIN) | Total Tension | # of Strands | Cable Diameter(ft)
1 | 602.7589204 | 154.9774219 | 125.58 | 28.08 | 865.1 | 37
2 | 567.4429176 | 206.6365625 | 134.94 | 37.44 | 1249.0 | 37
3 | 532.126994 | 206.6365625 | 134.94 | 37.44 | 1249.0 | 37
4 | 496.8111663 | 206.6365625 | 134.94 | 37.44 | 1249.0 | 37
5 | 461.4954567 | 206.6365625 | 134.94 | 37.44 | 1249.0 | 37
6 | 426.1798944 | 206.6365625 | 134.94 | 37.44 | 1249.0 | 37
7 | 390.8645195 | 206.6365625 | 134.94 | 37.44 | 1249.0 | 37
8 | 355.5493876 | 206.6365625 | 134.94 | 37.44 | 1249.0 | 37
9 | 320.2345794 | 206.6365625 | 134.94 | 37.44 | 1249.0 | 37
10 | 284.920215 | 206.6365625 | 134.94 | 37.44 | 1249.0 | 37
11 | 249.606483 | 206.6365625 | 134.94 | 37.44 | 1249.0 | 37
12 | 214.2936958 | 206.6365625 | 134.94 | 37.44 | 1249.0 | 37
13 | 178.9824127 | 206.6365625 | 134.94 | 37.44 | 1249.0 | 37
14 | 143.6737429 | 206.6365625 | 134.94 | 37.44 | 1249.0 | 37
15 | 108.3702405 | 206.6365625 | 134.94 | 37.44 | 1249.0 | 37
16 | 73.07939487 | 206.6365625 | 134.94 | 37.44 | 1249.0 | 37
17 | 37.8366383 | 206.6365625 | 134.94 | 37.44 | 1249.0 | 37
Axial Force in Deck
Section # | x from left end (ft) | Cable Tension (kip) | Axial Compression (kip)
1 | 15 | 865.1367269 | 1606.518571
2 | 45 | 828.9596228 | 3145.857946
3 | 75 | 828.9596228 | 3915.527633
4 | 105 | 828.9596228 | 4685.197321
5 | 135 | 828.9596228 | 5454.867008
6 | 165 | 828.9596228 | 6224.536696
7 | 195 | 828.9596228 | 6994.206383
8 | 225 | 828.9596228 | 7763.876071
9 | 255 | 828.9596228 | 8533.545758
10 | 285 | 828.9596228 | 9303.215446
11 | 315 | 828.9596228 | 10072.88513
12 | 345 | 828.9596228 | 10842.55482
13 | 375 | 828.9596228 | 11612.22451
14 | 405 | 828.9596228 | 12381.8942
15 | 435 | 828.9596228 | 13151.56388
16 | 465 | 828.9596228 | 13921.23357
17 | 495 | 828.9596228 | 14690.90326
 |  | * Add tandom load at first cable
Data to Plot Axial Compression
X | Y
15 | 1606.518571
45 | 1606.518571
45 | 3145.857946
75 | 3145.857946
75 | 3915.527633
105 | 3915.527633
105 | 4685.197321
135 | 4685.197321
135 | 5454.867008
165 | 5454.867008
165 | 6224.536696
195 | 6224.536696
195 | 6994.206383
225 | 6994.206383
225 | 7763.876071
255 | 7763.876071
255 | 8533.545758
285 | 8533.545758
285 | 9303.215446
315 | 9303.215446
315 | 10072.88513
345 | 10072.88513
345 | 10842.55482
375 | 10842.55482
375 | 11612.22451
405 | 11612.22451
405 | 12381.8942
435 | 12381.8942
435 | 13151.56388
465 | 13151.56388
465 | 13921.23357
495 | 13921.23357
495 | 14690.90326
525 | 14690.90326

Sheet: Tower Moment & shear
height | axial | moment | Shear | number
190 | 2865 | 544350 |  | 0
181.67 | 2865 | 520484.55 |  | 1 | 2865
173.34 | 2865 | 496619.1 |  | 2
165.01 | 2865 | 472753.65 |  | 3
156.68 | 2865 | 448888.2 |  | 4
148.35 | 2865 | 425022.75 |  | 5
140.02 | 2865 | 401157.3 |  | 6
131.69 | 2865 | 377291.85 |  | 7
123.36 | 2865 | 353426.4 |  | 8
115.03 | 2865 | 329560.95 |  | 9
106.7 | 2865 | 305695.5 |  | 10
98.37 | 2865 | 281830.05 |  | 11
90.04 | 2865 | 257964.6 |  | 12
81.71 | 2865 | 234099.15 |  | 13
73.38 | 2865 | 210233.7 |  | 14
65.05 | 2865 | 186368.25 |  | 15
56.72 | 2865 | 162502.8 |  | 16
48.39 | 2865 | 138637.35 |  | 17
40.06 | 2865 | 114771.9 |  | 18
31.73 | 2865 | 90906.45 |  | 19
 |  | 6352564.5
 |  | after 15% | 7305449.175

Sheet: Total Dead load
DL Joist | 2.38
DL Girder | 2.12
# Joist | 318
DL(Total)Joist | 11352.6
DL(total) Girder | 7791
Total DL | 19143.6
Cable DL | 0
Section DL | 957.18
# cables (each side) | 20
Cable seperatio on the twoer | 8.333333333

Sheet: Notes
Note 1
Assume 2% reinforcment of total volume of slab
The number of lane to number of girder ratio | 0.5-1.5 (
Joist Spacing = joist tributary width
Joist tributary length = adjacent girder spacing
From center to side, number girder type 1 and type 2

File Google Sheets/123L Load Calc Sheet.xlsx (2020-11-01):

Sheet: Calculation Main
Preliminary Bridge Load Calculation
 | Analyzed w/t Matlab
 | Data Output
 | Data to be filled in
 | Discarded Data
Load Combo | 1.2D +1.6L
 | 1.4D
 |  | Tandom Point Load |  |  |  |  | Live Load Impact Factor
 |  | 2 x 25 kip @ 4 ft per lane |  | one 25 kip must be distributed to each edge girder |  |  | 0.65 | for > = 3 lines |  |  |  | 2.496 |  | I | 106.6666667 | 17.5
Calculation sheet correction |  |  |  |  | 210 |  |  |  |  |  |  |  |  |  |  |  |  |  |  |  |  | Design Load
Section | Structural Element |  |  | Tributary Area |  |  |  |  |  | Distributed Load |  |  |  | deflection | 0.0005210485854 | 18 |  |  | Service Load |  |  | Moment |  |  | Shear |  | Axial
 |  |  | Spacing (ft) | Tributary Width(ft) | Tributary Length(ft) | Tributary Area(sq. ft) | Depth (ft) | Material Unit Weight (plf except concrete(pcf)) | Self Weight /Tribuary Area(kip) | Dead Load (ksf) | Live Load (ksf) | Total Service Load (ksf) | Tandom Load (kip) | Tandom Load Location | Converted Distributed Load (klf) | Length Multiplication Factor | Width Multiplication Factor | Total Self Weight(kip) | Maximum Moment (k-ft) | Maximum Shear (kip) | Compression (kip) | LTB Moment Capacity (k-ft) | Local Buckling Moment Capacity (k-ft) | Sufficent? | Shear Capacity(kip) | Sufficent? | Axial Capacity (
Deck | 8" Slab | Concrete | - | 85 | 525 | 44625 | 0.6666666667 | 150 | 4462.5 | 0.1000 | 0.0294 | 0.1670 | - |  | 14.1936 | 1 | 1 | 4462.5
Deck | Pavement , needs data
Deck | Stringers | Steel W30x 391 | 14 | 14 | 30 | 420 | * Fill in if built-up section is used | 391 | 11.73 | 0.1279 | 0.0294 | 0.2005 | 81.25 | For 19' spacing, 5*25 kip at middle of joist for maximum moment; at one end for maximum shear | 2.806969412 | 18 | 5 | 1055.7 | 1534.53 | 123.35 |  | 5026.3 | 6041.7 | Yes | 1280.3 | Yes
Note A on dwg | Girder Type 1 | Built-up: 22x4 flange, 4 x 22 web | 30 | 30 | 85 | 2550 | * Fill in if built-up section is used | 898.33 | 76.35805 | 0.1579 | 0.0294 | 0.2364 | (75,100,75)*0.65 | @ 19', 3*25 = 75, @ 38', 4*25 = 100, @ 57' 3*25 = 75 for maximum moment; @19' 4*25 = 100, @38' 3*25 = 75', @57' 3*25 =75, for maximum shear | 7.092930454 | 1 | 17 | 1298.08685 | 8697.05 | 386.76 | - | 8736 | 20000 | Yes | 1280.3 | Yes
Note B on dwg | Girder Type 2 (Not Used) | Steel W30x261 | 19 | 19 | 25 | 475 | * Fill in if built-up section is used | 261 | 6.525 | 0.1137 | 0.0294 | 0.1835 |  |  | 3.485887059 | 21 | 2 | 0 | 272.33 | 43.57 | - | 3184 | 3929 | Yes | 831 | Yes
Deck | Bottom Deck (Not Used) | Steel 40 in x 40 in x 2.5 in | 12.5 | 12.5 | 85 | 1062.5 | * Fill in if built-up section is used | 1276.041667 | 108.4635417 | 0.2595 | 0.0294 | 0.3633 |  |  | 4.54127364 | 1 | 42 | 0.00 | 3395.68 | 87.90 | - | - | 19804 | Yes | - | Yes
Note C on dwg | Edge Girder | Box Steel HSS 5 x 4.5 x 0.75 in | - | 42.5 | 30 | 1275 |  | 1134 | 34.02 | 0.1846 | 0.0294 | 0.2684 | 50*0.65 | 2*25 = 50 at middle for maximum moment, and at one end for maximum shear | 11.40911814 | 17.5 | 2 | 1190.70 | 2668.04 | 607.90 | 17557.53633 |  | 11907 | Yes | - | Yes | 263300 | Yes
 |  |  |  |  |  |  |  |  |  |  |  |  |  |  |  |  |  | new moment | 1283.525791 |  |  |  |  |  | Allowable Deflection(in)
 |  |  |  |  |  | 342.2735443 |  |  |  |  |  | 22.81823629 | 684.5470886 |  |  | Total Loading | Dead Weight (kip) | 8006.98685 | Dead Load (in kip) | 0.1794 | Dead Load (ksf) = 10415/525/85 | P1 | 88.66163067 | not used | 27.1 | Dead
 |  |  |  |  |  |  |  |  |  |  |  |  |  |  |  |  | Live Load(kip) | 1310.4 | Live Load | 0.0294 | Live Load(ksf) =L20 | P2 | 43.57358824 | not used | 4.4 | Live
 |  |  |  |  |  |  |  |  |  |  |  |  | 688.5308365 |  |  |  | Total Load (kip) | 11705.02 | Total Load Combo | 0.2623 | Total Load Combo (ksf) = Total Load/525/85 | Reaction Force | 284.7501512 | not used | 31.5 | Total
 |  |  |  |  |  |  |  |  |  |  |  |  |  |  |  |  |  | 688.5308365
 |  |  |  |  |  |  |  |  |  |  |  |  |  |  |  |  |  | 137.7061673 |  | 900.4783499
 | *HSS 40inx40in 2.5 in wall thickness works Mu=19800 k-ft, Code has been Uploaded -Sam |  |  |  |  |  |  |  |  |  |  |  |  |  |  |  |  | 1353.022658 |  |  |  |  |  | Tandom Load per Cable(Reducted )
 |  |  |  |  |  |  |  |  |  |  |  |  |  |  |  |  |  |  |  | Weight of Cable | 136.59 | kips |  | 97.5 | 8.125 | Moment of Reducted Tandom on Tower
 | Tower Size (Diameter) | 18 ft (bottom) |  | 3 ft (top) |  |  |  |  |  |  |  |  |  |  |  |  |  |  |  | Weight of Tower | 2086.65 | kips
 | Steel Ratio | 0.02 |  |  |  |  |  |  |  |  |  |  |  |  |  |  |  |  |  |  |  | x228/
 | Concrete Material | 8 ksi |  |  |  |  |  |  |  |  |  |  |  |  |  |  |  |  | Calc for Cable | 11.14764211 | 27.86910529 | 794.2695006
 |  |  |  |  |  |  |  |  |  |  |  |  |  |  |  | Plus Tandom Load
 |  |  |  |  |  |  |  |  |  |  |  |  |  | cable | 334.4292634 | 383.1792634 |  |  | cable | 7972

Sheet: Factors
 | Dimensions |  |  |  |  | EQ load | WS |  | Steel
# Lanes | width(ft) | length (ft) |  |  |  | 15% | 50 psf
6 | 85 | 525
Reduction factors
 | Dynamic load allowance | Impact Factor |  |  |  | Steel section weights | Weights (k/ft)
 | Deck Joints-All Limit states | 0.75 |  |  |  | W30*261 | 0.261
 | Fatigue and Fracture Limit State | 0.15 |  |  |  | W30*391 | 0.391
 | All other limit State | 0.33 |  |  |  | W30*200 | 0.2
 | Live load reduction factor for all 6 lanes loaded simultaneously | 0.65 |  |  |  | L8*8*1.125 | 0.0569
Material Properties
 | Material | Rho(pcf)
 | Concrete | 150 |  |  |  |  |  |  | 32.8125
 | Steel | 490
Dead loads |  | Dimension
Material | Section | Structural Element | #/deck | total # | Width (ft) /* Tributary Width | Length(ft) | Volume(cu. ft) | Self Weight(kip) | Spacing (ft) | Tributary Area/ element(sq. ft) | Total Dead Load(kip) | Live Load(kip) | Total Load(kip) | Distributed Load(klp)
Concrete | Deck | 8" Slab | - | - | 85 | 525 | 29750 | 4462.5 | - | 12 ft / joist | 4462.5 | 2110.5 | 6573 | 12.5
 |  | Reinforcement (Note 1) | - | - | 85 | 525 | 595 | 291.55 | TBD | NA | 4754.05 | NA | 6864.55 | 13.1
Steel | Joists | W30*261 | 8 | 168 | 12 | 14 |  | 2411.64 | 12.5 | 175 | 26.9 | 2110.5 | 4522.53
 | Girders | W30*391 | 3 | 63 |  | 25 |  | 615.825 |  |  |  | 2110.5
 | Girders | W30*200 | 2 | 42 |  | 25 |  | 210 |  |  |  | 2110.5
 | Edge element | L8*8*1.125 | 2 | 42 |  | 25 |  | 59.745 |  |  |  | 2110.5
 | Total |  |  |  |  | 25 |  | 8051.26
Live loads | 0
Live load (k/f) | 3.9
Load Combinations | Kips |  |  |  |  |  |  |  |  | gider 1 | 744.7589412
1.2D+1.6L | 12937.512 |  |  |  |  |  |  |  |  | gider 2 | 1373.346912
1.4D | 11271.764 |  |  |  |  |  |  |  |  | gider 3 | 1364.431059
 |  |  |  |  |  |  |  |  |  | gider 4 | 1416.666176
 |  |  |  |  |  |  |  |  |  | gider 5 | 744.7589412
 |  |  |  | factor | reduction factor |  |  |  |  | gider 6 | 1373.346912
W14*159 | Joist | Dead | 1.159 | 1.2 | 0.65 |  |  |  |  | gider 7 | 1364.431059
 |  | Live | 5.43 | 1.6
 |  | Earthquake | 0.988 | 1
 |  | toal | 8.03 | klf | 2.3788 | only dead
 | girder | self dead | 2.12 klf
 |  | from joist (max) | 361.35 | 3 point load, one in middle
 |  | h | w | tf | tw |  | A
 |  | 96 | 48.7 | 4.2 | 2.5 | inches | 623.7
girder | Vmax | 211.8 | kips-ft
 | Mmax | 2448 | kips-ft
joist | Vmax | 60.225 | kips-ft
 | Mmax | 225.84375 | kips-ft

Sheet: Axial Force Diagram
Cable
 |  | Cable Design Tension (MT) (kip) |  |  |  | Cable Parameter
Cable # | Length (ft) | DL | LL(MAX) | LL(MIN) | Total Tension | # of Strands | Cable Diameter(mm)
1 | 602.7589204 | 171.5782896 | 125.58 | 28.08 | 909.7 | 37 | 109.9
2 | 567.4429176 | 228.7710529 | 134.94 | 37.44 | 1320.5 | 37 | 109.9
3 | 532.126994 | 228.7710529 | 134.94 | 37.44 | 1320.5 | 37 | 109.9
4 | 496.8111663 | 228.7710529 | 134.94 | 37.44 | 1320.5 | 37 | 109.9
5 | 461.4954567 | 228.7710529 | 134.94 | 37.44 | 1320.5 | 37 | 109.9
6 | 426.1798944 | 228.7710529 | 134.94 | 37.44 | 1320.5 | 37 | 109.9
7 | 390.8645195 | 228.7710529 | 134.94 | 37.44 | 1320.5 | 37 | 109.9
8 | 355.5493876 | 228.7710529 | 134.94 | 37.44 | 1320.5 | 37 | 109.9
9 | 320.2345794 | 228.7710529 | 134.94 | 37.44 | 1320.5 | 37 | 109.9
10 | 284.920215 | 228.7710529 | 134.94 | 37.44 | 1320.5 | 37 | 109.9
11 | 249.606483 | 228.7710529 | 134.94 | 37.44 | 1320.5 | 37 | 109.9
12 | 214.2936958 | 228.7710529 | 134.94 | 37.44 | 1320.5 | 37 | 109.9
13 | 178.9824127 | 228.7710529 | 134.94 | 37.44 | 1320.5 | 37 | 109.9
14 | 143.6737429 | 228.7710529 | 134.94 | 37.44 | 1320.5 | 37 | 109.9
15 | 108.3702405 | 228.7710529 | 134.94 | 37.44 | 1320.5 | 37 | 109.9
16 | 73.07939487 | 228.7710529 | 134.94 | 37.44 | 1320.5 | 37 | 109.9
17 | 37.8366383 | 228.7710529 | 134.94 | 37.44 | 1320.5 | 37 | 109.9
Axial Force in Deck
Section # | x from left end (ft) | Cable Tension (kip) | Axial Compression (kip) | Edge Girder Size (top x side x thickness, in x in x in)
1 | 15 | 909.6815295 | 1689.236193
2 | 45 | 900.4783499 | 3361.38251 | 12" x 78" x 2"
3 | 75 | 900.4783499 | 4197.455668
4 | 105 | 900.4783499 | 5033.528827
5 | 135 | 900.4783499 | 5869.601985 | 12" x 78" x 2"
6 | 165 | 900.4783499 | 6705.675144
7 | 195 | 900.4783499 | 7541.748303
8 | 225 | 900.4783499 | 8377.821461 | 12" x 78" x 2"
9 | 255 | 900.4783499 | 9213.89462
10 | 285 | 900.4783499 | 10049.96778
11 | 315 | 900.4783499 | 10886.04094 | 24" x 78"x 2"
12 | 345 | 900.4783499 | 11722.1141
13 | 375 | 900.4783499 | 12558.18725
14 | 405 | 900.4783499 | 13394.26041 | 24" x 78"x 2"
15 | 435 | 900.4783499 | 14230.33357
16 | 465 | 900.4783499 | 15066.40673
17 | 495 | 900.4783499 | 15902.47989 | 24" x 78"x 2"
 |  | * Add tandom load at first cable

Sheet: Tower Moment & shear
height | axial | moment | Shear | number
190 | 2865 | 544350 |  | 0
181.67 | 2865 | 520484.55 |  | 1 | 2865
173.34 | 2865 | 496619.1 |  | 2
165.01 | 2865 | 472753.65 |  | 3
156.68 | 2865 | 448888.2 |  | 4
148.35 | 2865 | 425022.75 |  | 5
140.02 | 2865 | 401157.3 |  | 6
131.69 | 2865 | 377291.85 |  | 7
123.36 | 2865 | 353426.4 |  | 8
115.03 | 2865 | 329560.95 |  | 9
106.7 | 2865 | 305695.5 |  | 10
98.37 | 2865 | 281830.05 |  | 11
90.04 | 2865 | 257964.6 |  | 12
81.71 | 2865 | 234099.15 |  | 13
73.38 | 2865 | 210233.7 |  | 14
65.05 | 2865 | 186368.25 |  | 15
56.72 | 2865 | 162502.8 |  | 16
48.39 | 2865 | 138637.35 |  | 17
40.06 | 2865 | 114771.9 |  | 18
31.73 | 2865 | 90906.45 |  | 19
 |  | 6352564.5
 |  | after 15% | 7305449.175

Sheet: Total Dead load
DL Joist | 2.38
DL Girder | 2.12
# Joist | 318
DL(Total)Joist | 11352.6
DL(total) Girder | 7791
Total DL | 19143.6
Cable DL | 0
Section DL | 957.18
# cables (each side) | 20
Cable seperatio on the twoer | 8.333333333

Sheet: Notes
Note 1
Assume 2% reinforcment of total volume of slab
The number of lane to number of girder ratio | 0.5-1.5 (
Joist Spacing = joist tributary width
Joist tributary length = adjacent girder spacing
From center to side, number girder type 1 and type 2

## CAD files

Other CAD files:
Design Dwg/04212017/123L/FINAL Framing Plan.dwg
Design Dwg/04212017/Drawing/FINAL Cross Section.dwg
Design Dwg/04212017/Drawing/New folder/Preliminary-Assignment_NEW.dwg
Design Dwg/Design Drawings 4-24 Leigh Anne/FINAL Cross Section.dwg
Design Dwg/drawing set 0426/Preliminary-Assignment.dwg
Design Dwg/Drawing Set 0428/FINAL Framing Plan.dwg
Design Dwg/FINAL Framing Plan.dwg
Design Dwg/New for Submittal/jbhkh.dwg
Design Dwg/New New New/jbhkh.DXF
Design Dwg/New New New/New folder/FINAL Framing Plan.dwg
Design Dwg/SUB/drawing set 0426/FINAL Cross Section.dwg
Design Dwg/SUB/FINAL Framing Plan.dwg
PDF/Preliminary-Assignment.dwg
Design Dwg/04212017/123L/Preliminary-Assignment.dwg
Design Dwg/04212017/Drawing/FINAL Framing Plan.dwg
Design Dwg/Design Drawings 4-24 Leigh Anne/Top View (1).dwg
Design Dwg/drawing set 0426/FINAL Framing Plan.dwg
Design Dwg/Drawing Set 0428/Top View (1).dwg
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

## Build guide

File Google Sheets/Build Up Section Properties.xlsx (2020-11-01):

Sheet: Plate Build Up
width, b (in) | thickness, t(in) | Area, A_i(sq.in) | y_i | y_i*A_i | N.A., y_bar | distance to N.A, y(in) | Ixxo (in^4) | Ixx (in^4) | Iyy (in^4) | Zxx (in^3) | Zyy (in^3)
22 | 4 | 88 | 28 | 2464 | 15 | 13 | 117.3333333 | 14989.33333 | 3549.333333 | 1144 | 484
4 | 22 | 88 | 15 | 1320 | 15 | 0 | 3549.333333 | 3549.333333 | 117.3333333 | 968 | 88.00000
22 | 4 | 88 | 2 | 176 | 15 | -13 | 117.3333333 | 14989.33333 | 3549.333333 | 1144 | 484
 |  | 264 |  | 3960
Unit Weight(plf) | Cross Section Area (sq.in) | Ixx (in^4) | Iyy (in^4) | Sxx (in^3) | Syy(in^3) | Zxx (in^3) | Zyy(in^3) | rxx (in) | ryy (in)
898.33 | 264 | 33528 | 7216 | 4191 | 656 | 3256 | 1056.0 | 11.27 | 5.23

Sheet: Box Build Up
1 | Top (in) | Side (in) | Thickness (in)
17-15 | 24 | 78 | 2
34 X 60 X 2
2
14 - 12
3 |  | Unit Weight (plf) | Cross Section Area (in^2) | I_xx (in^4) | I_yy (in^4) | Sxx (in^3) | Zxx (in^3) | rx(in) | ry(in)
2017-11-09 |  | 1333.888889 | 392 | 273730.6667 | 40522.66667 | 7018.735043 | 9124 | 26.42522501 | 10.16730789
4 |  |  |  |  |  | Fy(ksi) | 50
2017-08-06 |  |  |  |  |  | Mp | 456200
 |  |  |  |  |  | factored Mn (k-in) | 410580
5 |  |  |  |  |  | Factored Mn (k-ft) | 34215
2017-05-03
6
2-0

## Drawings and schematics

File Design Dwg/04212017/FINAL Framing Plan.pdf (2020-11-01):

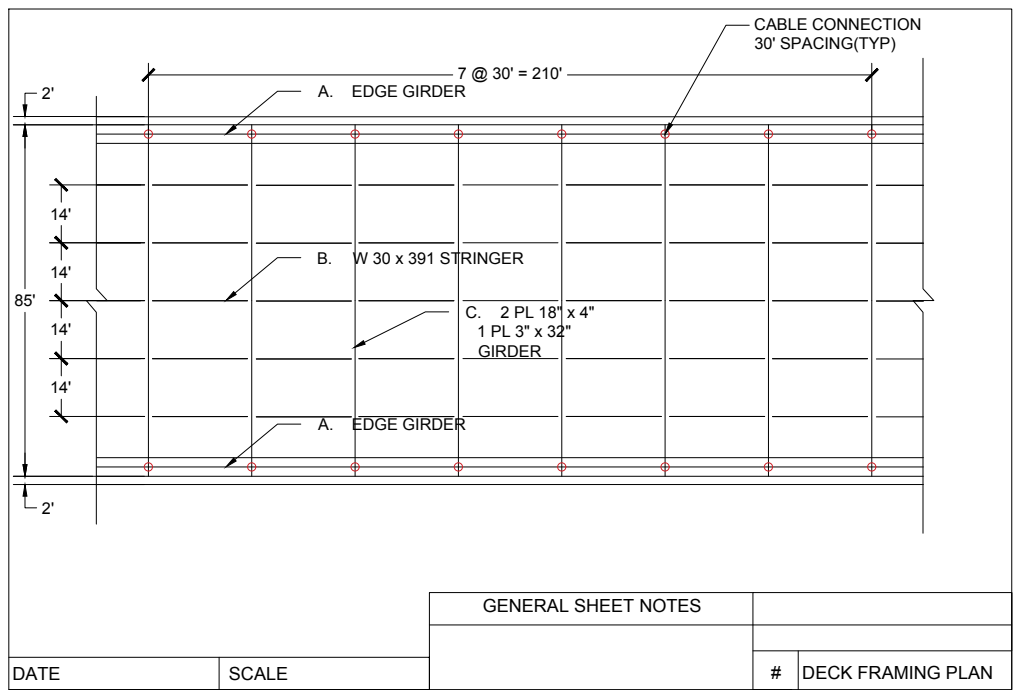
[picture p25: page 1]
CABLE CONNECTION 30' SPACING(TYP) 14' 14'; DECK FRAMING PLAN A. EDGE GIRDER B.; W 30 x 391 STRINGER C.; 2 PL 18" x 4" 1 PL 3" x 32" GIRDER A. EDGE GIRDER 14' 14' 85'; GENERAL SHEET NOTES; # 2' 2' DATE; SCALE

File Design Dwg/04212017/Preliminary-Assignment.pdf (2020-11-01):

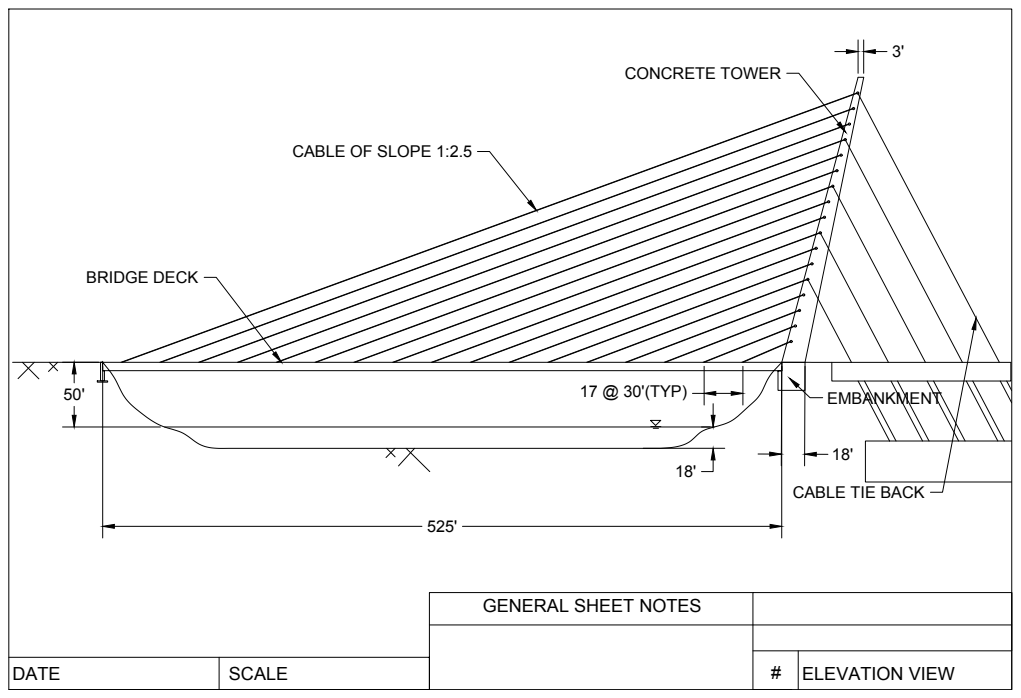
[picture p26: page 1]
EMBANKMENT CONCRETE TOWER BRIDGE DECK; ELEVATION VIEW CABLE OF SLOPE 1:2.5; 17 @ 30'(TYP) 525' 50'; CABLE TIE BACK 18' GENERAL SHEET NOTES DATE; SCALE

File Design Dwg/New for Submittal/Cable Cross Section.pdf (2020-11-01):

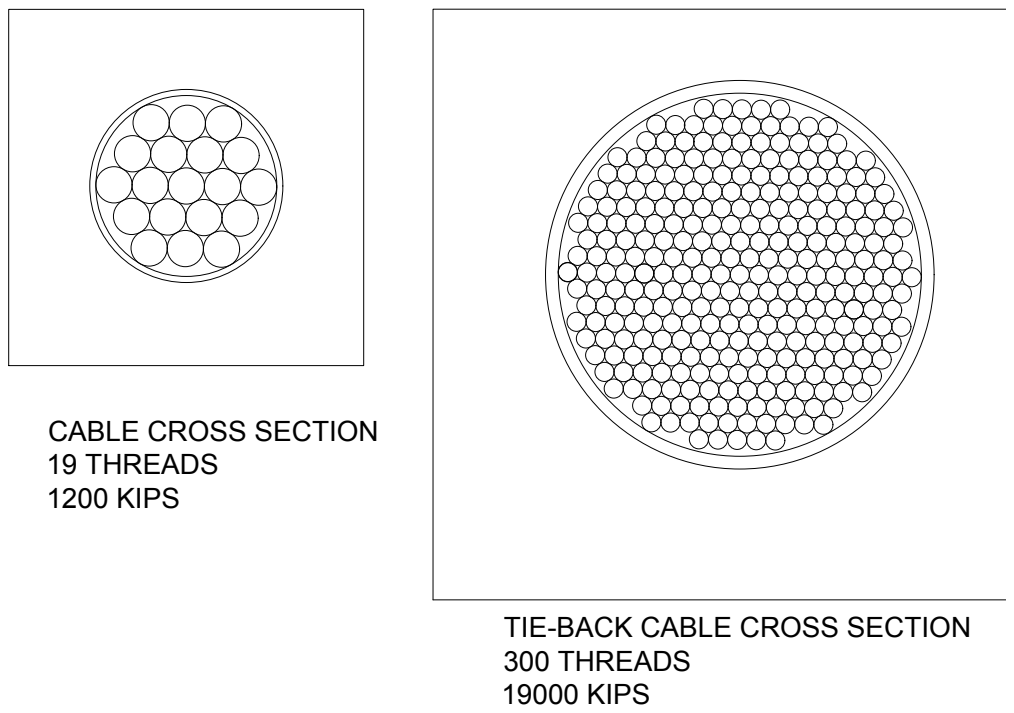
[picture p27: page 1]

TIE-BACK CABLE CROSS SECTION 300 THREADS 19000 KIPS CABLE CROSS SECTION 19 THREADS 1200 KIPS

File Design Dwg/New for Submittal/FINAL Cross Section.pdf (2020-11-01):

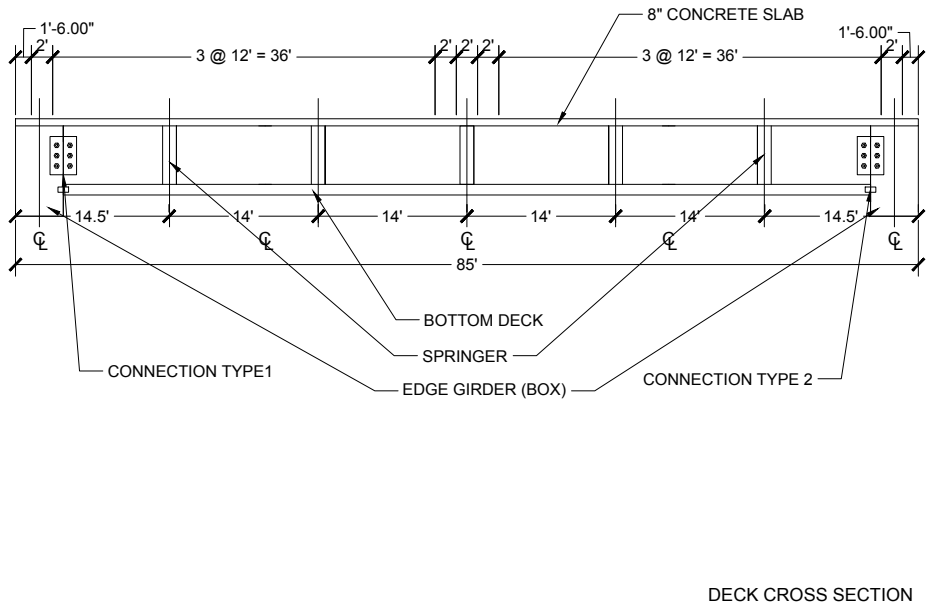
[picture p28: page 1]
DECK CROSS SECTION 1'-6.00" 2'; CL 8" CONCRETE SLAB EDGE GIRDER (BOX) SPRINGER CONNECTION TYPE1; CONNECTION TYPE 2 BOTTOM DECK 14.5'

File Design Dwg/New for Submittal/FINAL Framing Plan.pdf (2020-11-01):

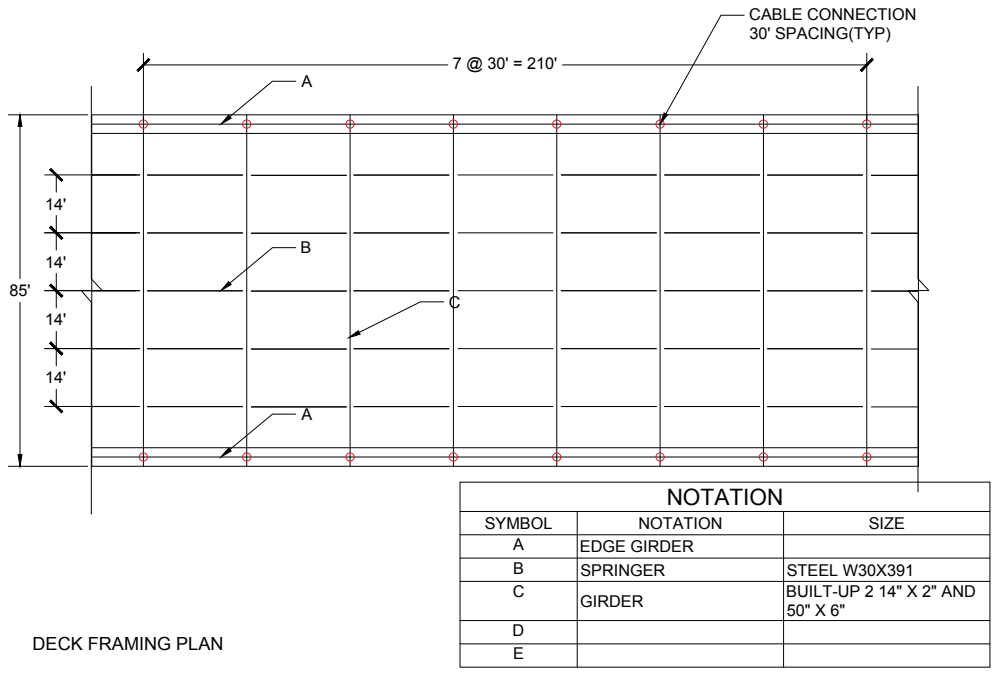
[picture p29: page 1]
CABLE CONNECTION 30' SPACING(TYP) 14' 14' DECK FRAMING PLAN; NOTATION SYMBOL; NOTATION; SIZE A; EDGE GIRDER B; SPRINGER; STEEL W30X391 C; GIRDER; BUILT-UP 2 14" X 2" AND 50" X 6" DE AB

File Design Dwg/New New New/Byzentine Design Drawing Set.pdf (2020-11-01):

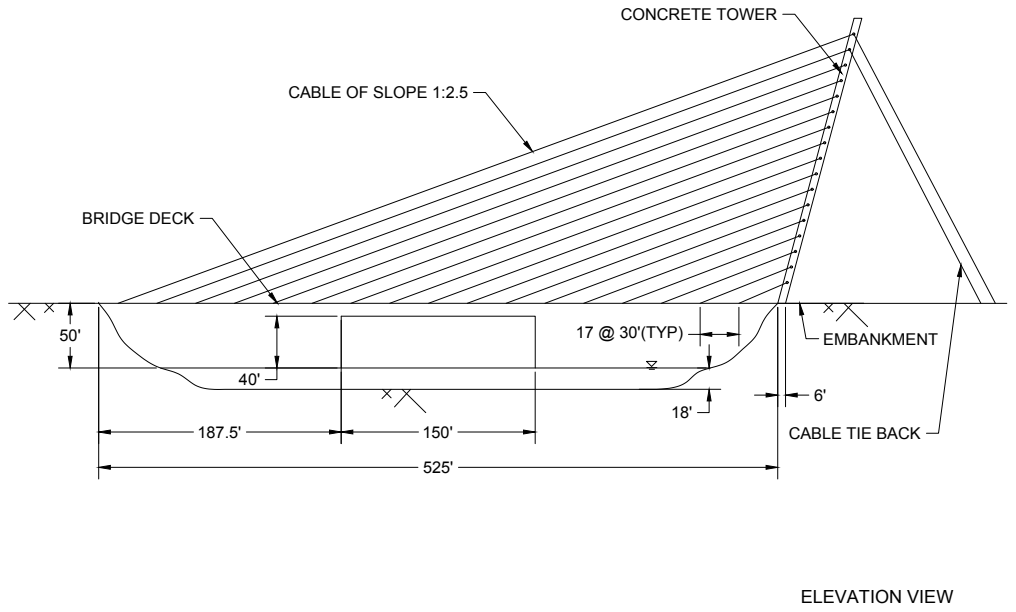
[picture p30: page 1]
EMBANKMENT CONCRETE TOWER BRIDGE DECK; ELEVATION VIEW CABLE OF SLOPE 1:2.5; 17 @ 30'(TYP) 525' 150' 40' 50'; CABLE TIE BACK 6'

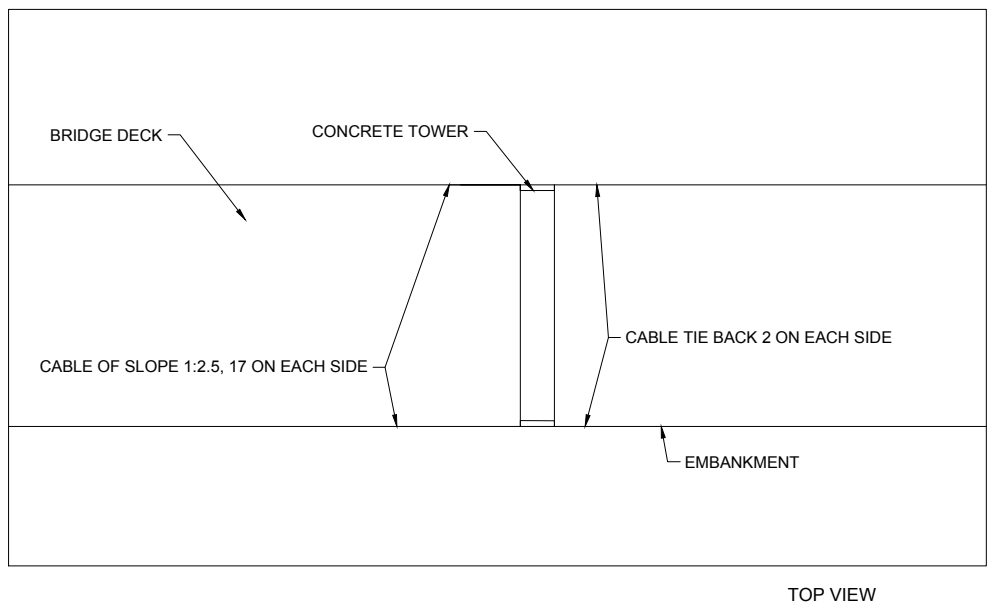
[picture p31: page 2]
TOP VIEW CONCRETE TOWER; EMBANKMENT BRIDGE DECK; CABLE TIE BACK 2 ON EACH SIDE CABLE OF SLOPE 1:2.5, 17 ON EACH SIDE

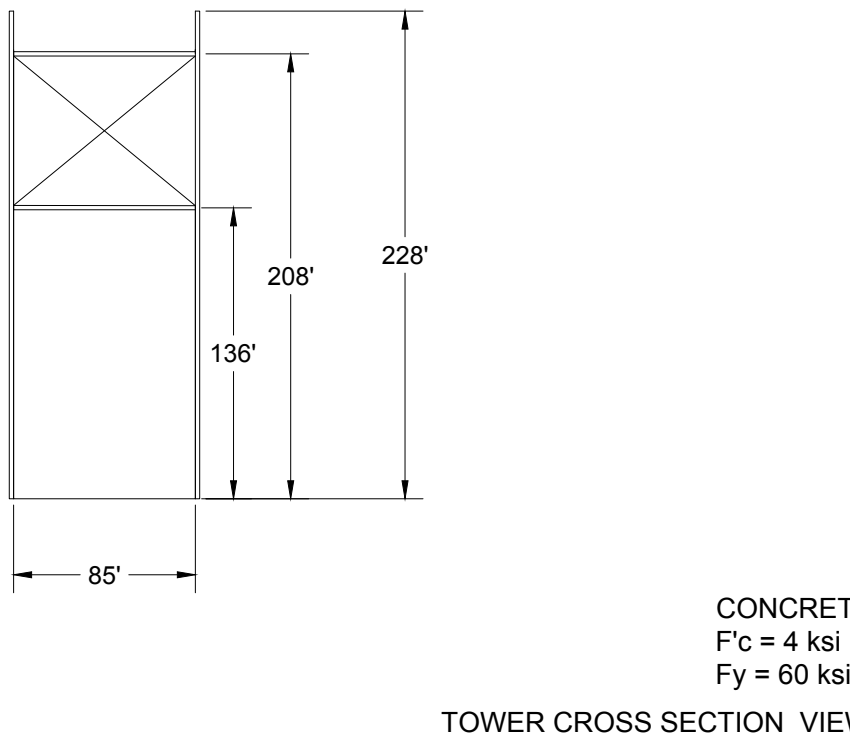
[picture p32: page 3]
TOWER CROSS SECTION VIEW 85'; CONCRETE F'c = 4 ksi Fy = 60 ksi

DECK CROSS SECTION 1'-6.00" 2'; CL 8" CONCRETE SLAB EDGE GIRDER (BOX) SPRINGER CONNECTION TYPE1; CONNECTION TYPE 2 BOTTOM DECK 14.5'

CABLE CONNECTION 30' SPACING(TYP) 14' 14' DECK FRAMING PLAN; NOTATION SYMBOL; NOTATION; SIZE A; EDGE GIRDER B; SPRINGER; STEEL W30X391 C; GIRDER; BUILT-UP 2 14" X 2" AND 50" X 6" DE AB


TIE-BACK CABLE CROSS SECTION 300 THREADS 19000 KIPS CABLE CROSS SECTION 19 THREADS 1200 KIPS

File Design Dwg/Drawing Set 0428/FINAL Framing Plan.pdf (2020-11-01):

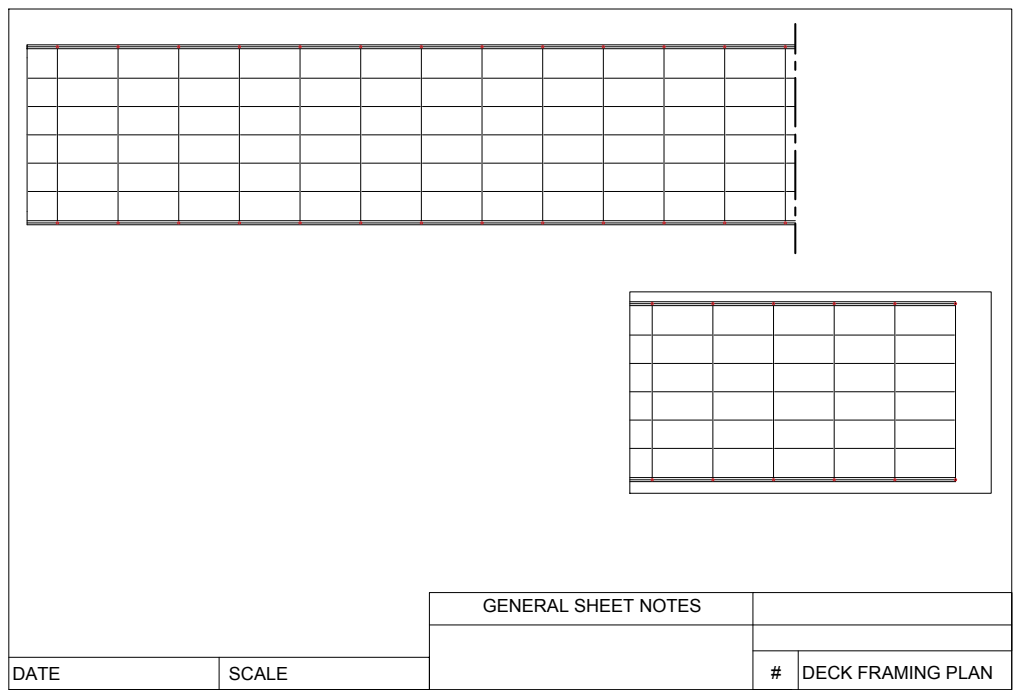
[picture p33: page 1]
DECK FRAMING PLAN GENERAL SHEET NOTES DATE; SCALE
